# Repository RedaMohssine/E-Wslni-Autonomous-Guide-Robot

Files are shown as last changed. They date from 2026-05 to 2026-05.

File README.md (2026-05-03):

# E-Wslni — Autonomous Campus Guide Robot

> **E-Wslni** (وصلني) is Moroccan Darija for *"Take me there"* — an autonomous indoor guide robot developed at [EMINES School of Industrial Management, UM6P](https://www.emines-ingenieur.org/) as a 1-year engineering capstone project.

---

## Table of Contents

- [Overview](#overview)
- [System Architecture](#system-architecture)
- [Modules](#modules)
  - [Hardware & Firmware](#hardware--firmware)
  - [SLAM Mapping](#slam-mapping)
  - [Autonomous Navigation — Nav2](#autonomous-navigation--nav2)
  - [AI Chatbot Interface](#ai-chatbot-interface)
- [In Action](#in-action)
- [Tech Stack](#tech-stack)
- [Getting Started](#getting-started)
  - [Prerequisites](#prerequisites)
  - [1 — SLAM Mapping](#1--slam-mapping)
  - [2 — Autonomous Navigation](#2--autonomous-navigation)
  - [3 — Chatbot Interface](#3--chatbot-interface)
- [Project Documents](#project-documents)
- [Repository Structure](#repository-structure)
- [Team](#team)

---

## Overview

E-Wslni is a full-stack autonomous guide robot that lets campus visitors ask questions or request navigation to any location by voice or text. The robot:

1. **Maps** the campus autonomously using a 2D LiDAR and SLAM
2. **Localizes** itself in real-time within that map
3. **Understands** natural-language requests in French, English, and Arabic
4. **Navigates** autonomously to the requested destination using Nav2
5. **Responds** via synthesized speech in the visitor's language

---

## System Architecture

The system is divided into four integrated layers:

| Layer | Technology | Role |
|---|---|---|
| **Hardware** | Arduino Mega 2560 + MPU-6050 | Low-level motor control, odometry, anomaly detection |
| **Compute** | Lenovo ThinkCentre Mini PC, Ubuntu 22.04) | Runs ROS2, SLAM, Nav2, vision |
| **Perception** | LD06 LiDAR + Logitech C920 camera | 360° 2D laser scanning + semantic obstacle detection |
| **Mapping / Navigation** | SLAM Toolbox + Nav2 | Real-time mapping & autonomous path planning |
| **Interface** | Streamlit + LangGraph + GPT-4o-mini | Conversational AI with voice I/O |

Communication between the chatbot (which can run on any machine) and the robot passes through a lightweight **FastAPI WebSocket hub** deployed on Railway.

---

## Modules

### Hardware & Firmware

**File:** [`arduino.ino`](arduino.ino)  
**Hardware:** Arduino Mega 2560, MPU-6050 IMU, 2× DC motors with quadrature encoders, 12 V Li-ion motor battery

The main firmware handles:

- **Differential drive control** — independent left/right DC motors, PWM + PID with feedforward, adaptive filtering
- **Wheel geometry** — wheel radius 0.10 m, wheelbase (entraxe) 0.488 m
- **Odometry** — quadrature encoders (64 CPR) sampled at 128 Hz; velocity published to ROS2 at 57600 baud
- **Anomaly detection** via MPU-6050:
  - Tilt / rollover detection (gyro X/Y rates)
  - Floor bump detection (accelerometer Z deviation from baseline)
  - Wheel-slip detection (gyro yaw vs. encoder-computed yaw divergence); PID gain reduced to 60 % on slip
- **Battery management** — 12 V Li-ion monitoring with relay cutoff at 11 V (motors disconnected during charge)
- **Angular correction loop** — PI controller (Kp=0.8, Ki=1.5) to compensate mechanical asymmetries
- **Serial protocol** — speed + angular velocity commands; telemetry at 128 Hz

**CAD Design:** [`SolidWorks CAD/`](SolidWorks%20CAD/)  
60+ SolidWorks parts and assemblies covering the octagonal chassis (HPL 8 mm panels, steel square-tube frame), motor mounts, wheel sub-assemblies (axle + pillow-block bearings + flexible coupling), LiDAR/screen enclosure, camera support, charging port, and the automatic charging station.

| Real Robot | SolidWorks CAD Model |
|:---:|:---:|
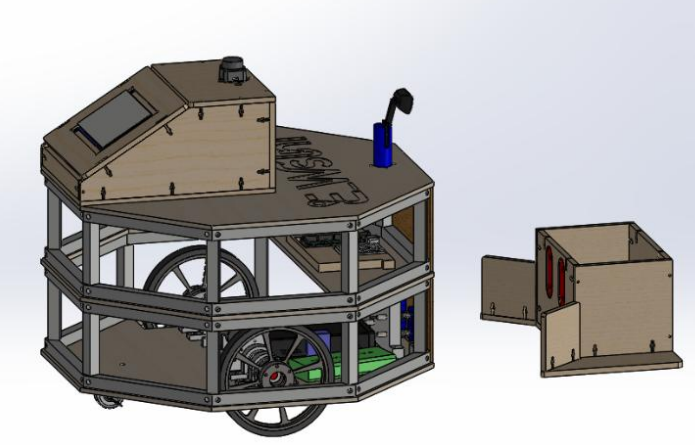
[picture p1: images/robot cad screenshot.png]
SolidWorks full-assembly render of E-Wslni showing chassis layers, wheel assembly, and electronics enclosure
| E-Wslni — octagonal laser-cut chassis with LD06 LiDAR and electronics box on top |  |
| *The physical robot: octagonal laser-cut chassis, dual DC drive wheels, and the electronics enclosure housing the LD06 LiDAR on top.* | *SolidWorks full assembly — chassis layers, motor mounts, drive wheels, LiDAR mount, and the detachable electronics box.* |

---

### SLAM Mapping

**Directory:** [`Mapping (SLAM)/`](Mapping%20(SLAM)/)  
**Stack:** ROS2 Humble · SLAM Toolbox · LD06 LiDAR · Arduino Uno

The SLAM module builds a persistent 2D occupancy map of the campus while the operator teleoperates the robot.

#### Key files

| File | Role |
|---|---|
| `src/ldlidar_stl_ros2/` | LD06 LiDAR ROS2 driver (C++) — publishes `/scan` at 230400 baud |
| `scripts/arduino_bridge.py` | Reads encoder ticks from Arduino, publishes `/odom` with differential drive kinematics |
| `scripts/keyboard_teleop.py` | AZERTY keyboard teleoperation for manual mapping runs |
| `hardware_r/robot_control.ino` | Arduino Uno sketch used during SLAM (speed + steering protocol) |
| `config/mapper_params_online_async.yaml` | SLAM Toolbox parameters (resolution, range, loop closure) |
| `config/slam_toolbox.rviz` | RViz layout for real-time map visualization |
| `launch/robot_slam_launch.py` | All-in-one launch: LiDAR + Arduino bridge + SLAM Toolbox |

#### TF tree

```
map → odom → base_footprint → base_link → base_laser
```

#### Quick start

```bash
# 1. Give serial permissions (once)
sudo chmod 666 /dev/ttyUSB0 /dev/ttyACM0
# or install persistent udev rules:
sudo bash scripts/create_udev_rules.sh

# 2. Upload robot_control.ino to Arduino Uno via Arduino IDE

# 3. Build the ROS2 workspace
cd "Mapping (SLAM)/ld06_reel_plateforme_mobile/LD06_SLAM_Robot_Clean"
source /opt/ros/humble/setup.bash
rosdep install --from-paths src --ignore-src -y
colcon build --symlink-install
source install/setup.bash

# 4. Launch everything
ros2 launch launch/robot_slam_launch.py

# 5. Teleoperate with AZERTY keyboard (separate terminal)
python3 scripts/keyboard_teleop.py
```

| Key | Action |
|-----|---|
| `Z` | Forward |
| `S` | Backward |
| `Q` | Turn left |
| `D` | Turn right |
| `Space` | Stop |

#### Save the map

```bash
ros2 run nav2_map_server map_saver_cli -f ~/campus_map
# Produces: campus_map.pgm + campus_map.yaml
```

#### Result — EMINES campus map

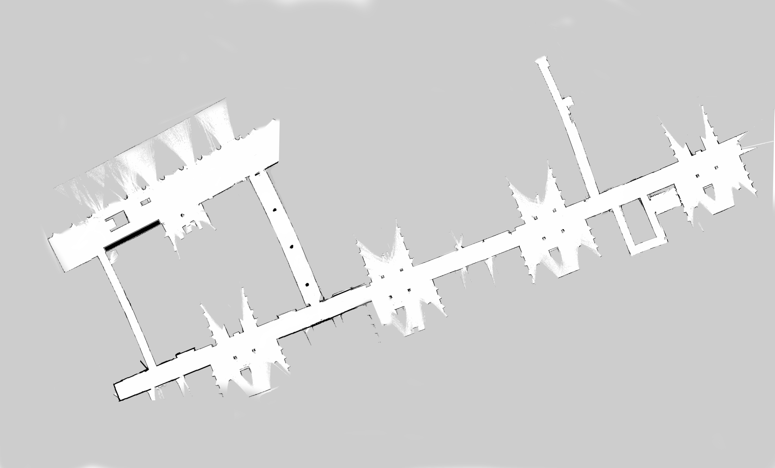
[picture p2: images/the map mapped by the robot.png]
2D occupancy map of the EMINES campus corridors and rooms, generated by SLAM Toolbox with the LD06 LiDAR


*Full occupancy map of the EMINES building generated during a teleoperated mapping run. White = free space, black = walls/obstacles, grey = unexplored. The map captures the main corridors, room doorways, and open areas across the floor.*

---

### Autonomous Navigation — Nav2

**Directory:** [`Navigation (NAV2)/`](Navigation%20(NAV2)/)  
**Stack:** ROS2 Humble · Nav2 · Gazebo (simulation) · pre-built campus map

The navigation module uses the map saved during SLAM to localize the robot (AMCL) and plan collision-free paths to goal positions sent by the chatbot.

#### Key source packages

| Package | Role |
|---|---|
| `robot_hardware/` | Translates Nav2 `cmd_vel` → Arduino serial commands; publishes encoder odometry |
| `robot_navigation/` | Nav2 parameter file (`nav2_params.yaml`) and launch |
| `robot_navigation2/` | Alternative Nav2 configurations (localization-only, minimal, complete) |
| `robot_simulation/` | Gazebo world + robot URDF for simulation-based testing |

#### Utility scripts

| Script | Purpose |
|---|---|
| `map_scale_calibrator.py` | Interactive GUI — click known distances on the PGM map to calibrate resolution |
| `teamviewer.py` | Terminal HUD with real-time speed/turn bars for manual control |

#### Nav2 in action — local costmap and trajectory planning

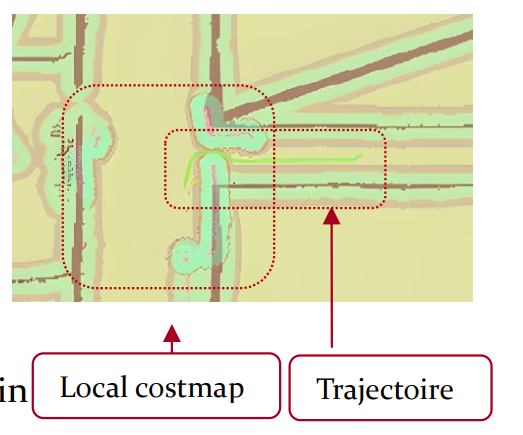
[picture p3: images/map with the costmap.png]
Nav2 local costmap overlaid on the campus map, with the planned trajectory shown through a corridor


*Nav2 running on the real robot: the coloured overlay is the **local costmap** (inflation layers around obstacles in green/brown), and the planned **trajectory** shows the route the robot is following through the corridor. The DWB planner replans dynamically at each control step.*

#### Quick start (real robot)

```bash
cd "Navigation (NAV2)/slam"
source /opt/ros/humble/setup.bash
source test/install/setup.bash

# Launch navigation with saved map
ros2 launch robot_hardware real_robot_nav.launch.py map:=test/maps/slam_map.yaml
```

#### Quick start (simulation)

```bash
cd "Navigation (NAV2)/slam/test"
source /opt/ros/humble/setup.bash
source install/setup.bash

ros2 launch robot_simulation gazebo.launch.py
ros2 launch robot_navigation2 nav2.launch.py use_sim_time:=true
```

---

### AI Chatbot Interface

**Directory:** [`UI + Chatbot/`](UI%20+%20Chatbot/)  
**Stack:** Streamlit · LangGraph · LangChain · OpenAI GPT-4o-mini · Whisper · Cartesia · Chroma · FastAPI

The chatbot is a Streamlit web application that gives visitors a conversational interface — by text or voice — to query the campus knowledge base and request autonomous navigation.

#### Architecture

```
User (browser)
    │  voice / text
    ▼
Streamlit UI  ──────────────────────────────────────┐
    │                                                │
    ▼                                                │
LangGraph Workflow                                   │
    ├─ AudioWorkflow: STT (Whisper) → LLM → TTS     │
    └─ ChatWorkflow:  text → LLM                     │
              │                                      │
              ▼                                      │
         GPT-4o-mini (tool use)                      │
          ├─ document_retriever  ←── Chroma RAG      │
          └─ navigation_tool                         │
                    │                                │
                    ▼                                │
            FastAPI Hub (Railway) ◄──────────────────┘
                    │
                    ▼
              Robot (Nav2 goal)
```

#### User Interface

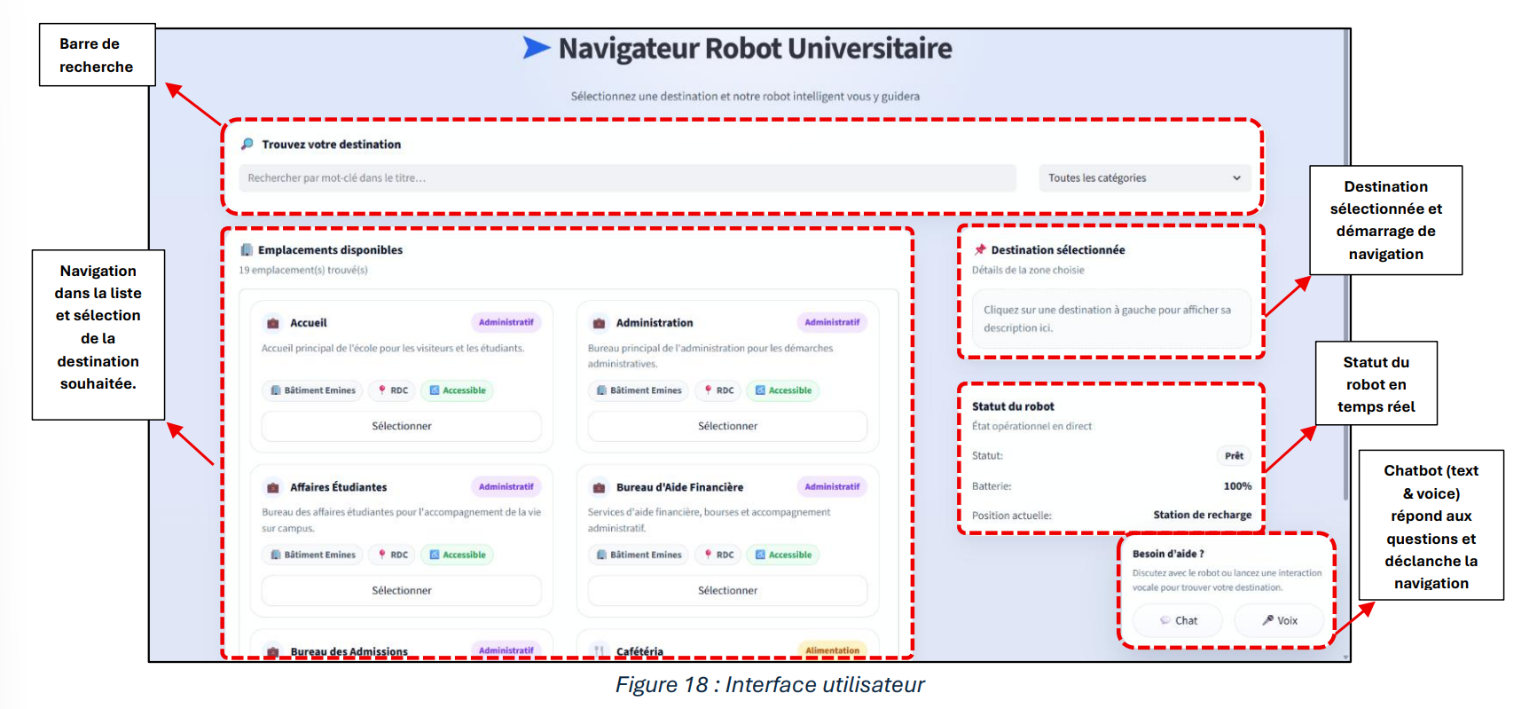
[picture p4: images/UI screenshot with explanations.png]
Streamlit chatbot UI — destination search panel, locations list, robot status card, and the voice/chat assistant widget


*The desktop interface — **"Navigateur Robot Universitaire"**:*
- **(Left) Location browser** — searchable list of all 19+ campus destinations, filterable by category (Administrative, Food, Labs, Clubs…). Click any card to select it.*
- **(Top-right) Destination panel** — shows details of the selected destination and triggers navigation on the robot.*
- **(Mid-right) Robot status** — live connection status, battery level, and current position reported by the robot.*
- **(Bottom-right) AI Assistant** — switch between **Chat** (text) and **Voice** modes. Voice input is transcribed by Whisper, answered by GPT-4o-mini in the visitor's language (FR/EN/AR), and spoken back through the robot's speaker via Cartesia TTS.*

#### Key files

| File | Role |
|---|---|
| `streamlit_app.py` | Entry point |
| `src/workflow.py` | LangGraph state machine — routes audio/text, calls tools |
| `src/services/llm.py` | GPT-4o-mini agent with two tools: RAG retrieval + navigation dispatch |
| `src/services/navigation.py` | Fuzzy location matching + WebSocket dispatch to robot |
| `src/services/rag.py` | OpenAI embeddings + Chroma vector search over campus docs |
| `src/services/stt.py` | Whisper-1 speech-to-text with campus proper-noun prompt biasing |
| `src/services/tts.py` | Cartesia text-to-speech (French/English/Arabic routing) |
| `src/services/memory.py` | Conversation history persistence |
| `src/ui/app_desktop.py` | Main Streamlit page — chat widget, voice orb, navigation card |
| `hub/main.py` | FastAPI WebSocket relay between chatbot and robot |
| `vectordb_generation.py` | One-time script to index campus documents into Chroma |
| `data/locations.json` | Campus destinations catalog (name, aliases, coordinates, category) |
| `data/*.md` | EMINES programs and campus knowledge base |

#### Setup

```bash
cd "UI + Chatbot"
python -m venv .venv
source .venv/bin/activate          # Windows: .venv\Scripts\activate
pip install -e .
```

Create a `.env` file:

```env
OPENAI_API_KEY=sk-...
ASSEMBLYAI_API_KEY=...
CARTESIA_API_KEY=...
HUB_URL=wss://your-hub.railway.app/ws/robot   # optional: only for live robot
HUB_TOKEN=...                                   # optional
```

Build the RAG index (first time only):

```bash
python vectordb_generation.py
```

Run the app:

```bash
streamlit run streamlit_app.py
```

#### Deploy the hub (Railway)

```bash
cd hub
# Push to Railway — Procfile and railway.json are included
```

---

## In Action

The robot navigating autonomously through EMINES corridors and doorways:

| Approaching a doorway | Crossing through |
|:---:|:---:|
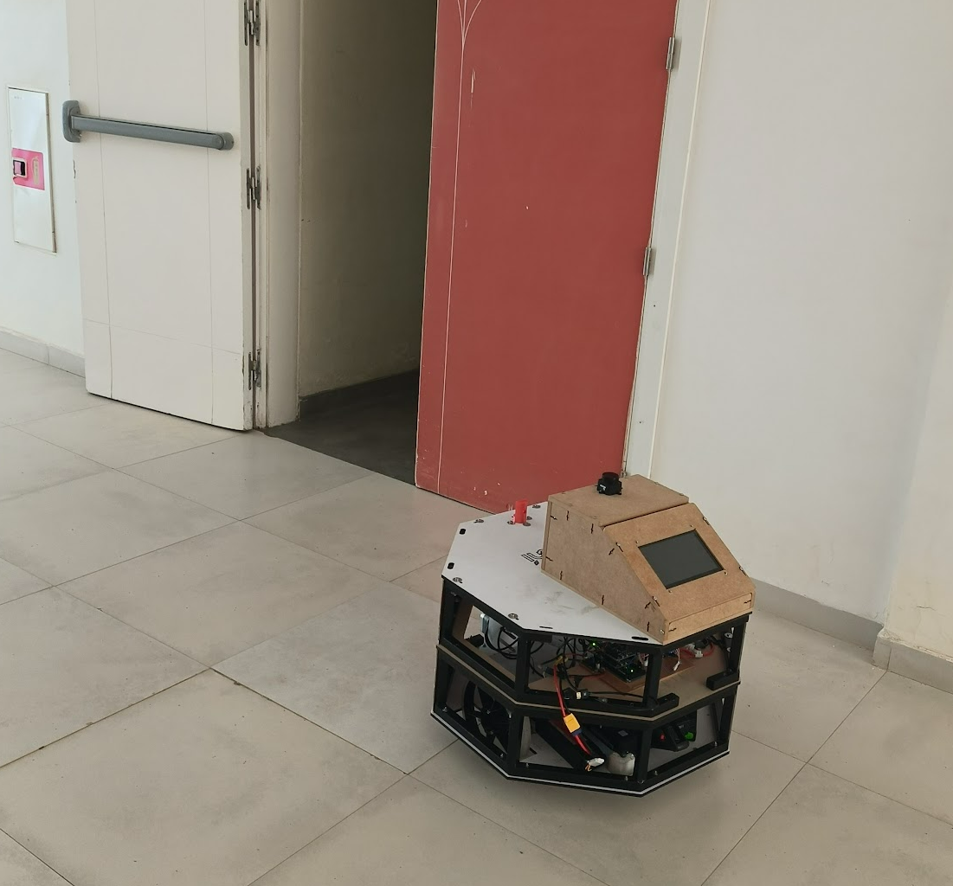
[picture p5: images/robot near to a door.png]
E-Wslni approaching an open doorway in an EMINES corridor, aligned by the Nav2 local planner
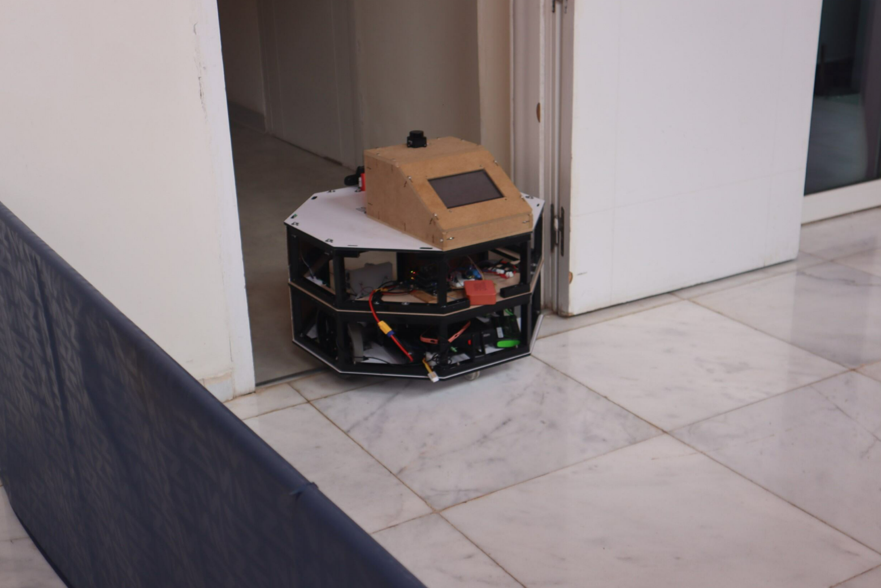
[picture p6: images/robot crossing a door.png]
E-Wslni successfully crossing through a doorway, demonstrating narrow-passage navigation
|  |  |
| *Robot approaching an open doorway — the Nav2 local planner aligns the robot with the gap while continuously replanning around the door-frame obstacle.* | *Robot threading through the doorway — demonstrating the clearance margins achieved by the DWB planner and the differential drive kinematics.* |

---

## Tech Stack

| Domain | Technology |
|---|---|
| Robot OS | ROS2 Humble (Ubuntu 22.04) |
| SLAM | SLAM Toolbox |
| Navigation | Nav2 (costmaps, DWB planner, AMCL) |
| Simulation | Gazebo |
| LiDAR | LD06 (12 m range, 360°, 10 Hz) |
| Microcontroller | Arduino Mega 2560 |
| IMU | MPU-6050 (gyro + accelerometer) |
| LLM | OpenAI GPT-4o-mini |
| Orchestration | LangChain + LangGraph |
| Vector DB | Chroma |
| STT | OpenAI Whisper-1 |
| TTS | Cartesia |
| UI Framework | Streamlit |
| Hub | FastAPI + WebSockets (Railway) |
| CAD | SolidWorks |
| Languages | Python 3.11 · C++ · C (Arduino) |

---

## Getting Started

### Prerequisites

- **Ubuntu 22.04** for the robot (ROS2 / Nav2)
- **Python 3.11+** for the chatbot (any OS)
- **ROS2 Humble** — [install guide](https://docs.ros.org/en/humble/Installation.html)
- **Arduino IDE** — for firmware upload
- API keys: OpenAI, Cartesia

### 1 — SLAM Mapping

See [SLAM Mapping](#slam-mapping) section above.

### 2 — Autonomous Navigation

See [Autonomous Navigation](#autonomous-navigation--nav2) section above.

### 3 — Chatbot Interface

See [AI Chatbot Interface](#ai-chatbot-interface) section above.

---

## Project Documents

The full technical documentation for this project is included at the root of the repository:

| Document | Description |
|---|---|
| [📄 Dossier de définition](Dossier%20de%20d%C3%A9finition.pdf) | Project definition document — functional requirements, system specifications, design choices, and technical architecture |
| [📊 Présentation soutenance 2](Pr%C3%A9sentation%20soutenance%202%20guide%20intelligent.pdf) | Final presentation slides — project overview, results, and demonstrations |

---

## Repository Structure

```
Autonomous-Guide-Robot-E-Wslni/
│
├── arduino.ino                          # Arduino Mega 2560 main firmware
├── Dossier de définition.pdf            # Project definition document
├── Présentation soutenance 2 guide intelligent.pdf
│
├── images/                              # Project photos and screenshots
│   ├── robot image .JPG                 # Physical robot photo
│   ├── robot cad screenshot.png         # SolidWorks CAD render
│   ├── the map mapped by the robot.png  # SLAM occupancy map result
│   ├── map with the costmap.png         # Nav2 costmap + trajectory
│   ├── UI screenshot with explanations.png  # Annotated chatbot UI
│   ├── robot near to a door.png         # Robot approaching a doorway
│   ├── robot crossing a door.png        # Robot crossing a doorway
│   └── photo of our team and professors.JPG # Team photo
│
├── SolidWorks CAD/                      # 60+ mechanical parts & assemblies
│
├── Mapping (SLAM)/
│   └── ld06_reel_plateforme_mobile/
│       └── LD06_SLAM_Robot_Clean/
│           ├── src/ldlidar_stl_ros2/    # LD06 LiDAR ROS2 driver (C++)
│           ├── scripts/
│           │   ├── arduino_bridge.py    # Odometry publisher (Ackermann kinematics)
│           │   └── keyboard_teleop.py   # Manual AZERTY teleoperation
│           ├── config/                  # SLAM Toolbox + RViz configs
│           ├── launch/                  # ROS2 launch files
│           └── hardware_r/
│               └── robot_control.ino    # Arduino Uno SLAM-mode firmware
│
├── Navigation (NAV2)/
│   └── slam/
│       ├── map_scale_calibrator.py      # Map resolution calibration GUI
│       ├── teamviewer.py                # Interactive terminal controller
│       └── test/src/
│           ├── robot_hardware/          # cmd_vel → Arduino, encoder odometry
│           ├── robot_navigation/        # Nav2 parameter files
│           ├── robot_navigation2/       # Nav2 launch configurations
│           └── robot_simulation/        # Gazebo world + robot URDF
│
└── UI + Chatbot/
    ├── streamlit_app.py                 # Entry point
    ├── vectordb_generation.py           # RAG index builder
    ├── hub/main.py                      # FastAPI WebSocket relay (Railway)
    ├── src/
    │   ├── workflow.py                  # LangGraph state machine
    │   ├── models.py                    # Data models
    │   ├── services/                    # LLM · RAG · STT · TTS · Navigation · Memory
    │   ├── ui/                          # Streamlit pages & CSS
    │   └── components/                  # Custom voice orb component
    └── data/
        ├── locations.json               # Campus destinations catalog
        └── *.md                         # EMINES campus knowledge base
```

---

## Team

Developed at **EMINES School of Industrial Management — UM6P** (2024–2025).

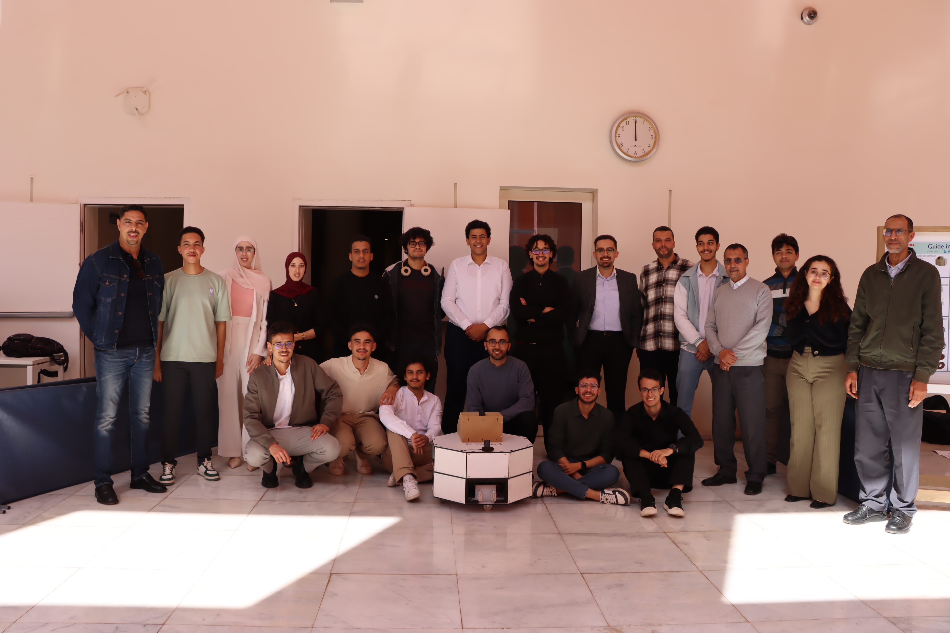
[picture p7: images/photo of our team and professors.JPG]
The E-Wslni project team and supervising professors gathered around the robot at EMINES, UM6P, Ben Guerir


*The E-Wslni team and supervising professors at EMINES — Université Mohammed VI Polytechnique, Ben Guerir, Morocco.*

<!-- Add your team members here -->
<!--
| Name | Role |
|---|---|
| ... | ... |
-->

---

*EMINES — École De Management Industriel, Université Mohammed VI Polytechnique, Ben Guerir, Morocco.*

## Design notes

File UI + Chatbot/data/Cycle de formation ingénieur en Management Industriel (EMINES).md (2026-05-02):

# Contexte de la création de l’Emines

L’Afrique est une multitude. Cet immense continent, berceau de l’humanité, comptant cinquante-quatre états, deux mille langues, mille groupes ethniques, trente millions de kilomètres carrés et une population qui devrait doubler d’ici 2050, est un espace complexe, qui doit faire face à des défis majeurs pour consolider sa propre dynamique de développement. La révolution numérique actuelle qui transforme les chaînes de valeur au niveau mondial et le développement des compétences est un de ces défis.

Pour l’Afrique, c’est l’opportunité d’être créatrice de valeur dans les industries traditionnelles telles que le secteur manufacturier, mais également dans d’autres secteurs et activités essentiels au développement industriel tels que la logistique, l’agriculture, l’énergie, les communications, les services, la croissance verte et les villes intelligentes. Le continent africain, fort de son histoire et de son potentiel, dispose d’un ensemble d’atouts majeurs pour inventer son propre modèle d’industrialisation durable.

Pour cela, ce continent doit transformer ses modèles d’éducation afin de former les talents qui contribueront à écrire cet avenir. Il doit notamment pouvoir s’appuyer sur des ingénieurs de haut niveau scientifique, inventifs, créatifs et entrepreneurs qui sauront conduire le progrès en Afrique.

# Vocation de l’EMINES :

L’EMINES - School of Industrial Management a pour vocation de :
- **Former les futurs leaders des entreprises**
Des ingénieurs-managers maîtrisant les savoirs scientifiques/techniques de base et préparés à l'entrepreneuriat panafricain
- **Développer une recherche impactante**
Programmes de recherche alignés sur les besoins concrets des entreprises africaines

Pour répondre à ces deux missions, la School of Industrial Management base son développement sur :
- **Formations pratiques :** Une pédagogie résolument orientée projets en équipe et au moins 42 semaines de stage dont un tiers à l'étranger
- **Recherche appliquée :** Partenariats entreprises avec utilisation d'outils de simulation pour résoudre des problèmes réels
- **Excellence académique :** Collaboration avec MINES Paris - PSL, Ecole Polytechnique ainsi qu'un réseau international d'enseignants-chercheurs
- **Culture entrepreneuriale :** Préparation aux réalités économiques mondiales et développement de compétences multiculturelles

# Le profil des ingénieurs de l’EMINES découle logiquement de cette vocation/ PROFIL DE L'INGENIEUR DE L'EMINES :

DIGITAL, INTERCULTUREL, ENTREPRENEUR, MANAGER, SCIENTIFIQUE

Au sein de l’Université Mohammed 6 Polytechnique (UM6P), l’EMINES met ainsi en œuvre deux principes fondateurs de cette université: le développement des talents au service de l’Afrique et une pédagogie originale basée sur le learning by doing.

L'EMINES offre ainsi à ses élèves-ingénieurs une formation fondamentale scientifique, technique et socio-économique, marquée par l'excellence académique, appuyée sur un fort développement de savoir-faire pratique et de savoir-être.
Sa Majesté le Roi Mohammed VI a procédé jeudi 12/01/2017 à l’inauguration de l’Université Mohammed VI Polytechnique.

# Campus de l’EMINES – UM6P :
Au-delà de la vie académique, l’EMINES-School of Industrial Management est un véritable espace de vie en communauté, qui est situé sur le campus de 35 hectares de l’Université Mohammed VI Polytechnique au cœur de la future ville verte de Benguérir et à proximité de Marrakech.

Ce campus offre une qualité d’<u>hébergement et de restauration</u> aux standards internationaux.
Par ailleurs, il permet une pratique active du sport qui est une composante importante de la pédagogie de la School of Industrial Management.

**Les installations sportives :**
Le campus dispose d’infrastructures sportives de grande qualité, en intérieur et en extérieur.
* 5000 m² de terrains sportifs en plein air dont :
    - 2 terrains de mini foot gazonnés
    - 4 terrains omnisport (tennis, basket, volley hand-ball)
* Une piscine semi olympique de 25 m et un bassin d’apprentissage
* Une salle de fitness
* Une salle de musculation
* Une salle de danse
* Une salle de sport de combat

Enfin, La bibliothèque est située au coeur de la vie de la School of Industrial Management.
Son but est de favoriser l'accès à la culture, à la connaissance et à l'information scientifique et technique.

Elle propose pour l'instant environ 12 000 ouvrages couvrant tous les domaines de spécialités de l'école, ainsi qu'une collection d'ouvrages de culture générale (romans, littérature, revues, histoire...). Lien direct vers <u>le site de la Bibliothèque</u> : https://learningcenter.um6p.ma/

Le fonds documentaire est répertorié dans une base de données. Les étudiants, enseignants et chercheurs de l'école peuvent consulter le catalogue en ligne de n'importe quel point du campus.

Enfin, une équipe de documentalistes se tient à la disposition des utilisateurs pour les accueillir, les informer, les guider dans leurs recherches, et recueillir leurs suggestions.

# Accessibilité et transports
<table>
  <tbody>
    <tr>
        <td>EMINES</td>
        <td>-</td>
        <td>Université Mohammed VI Polytechnique</td>
    </tr>
    <tr>
        <td>LOT 660</td>
        <td>-</td>
        <td>HAY MOULAY RACHID</td>
    </tr>
    <tr>
        <td>43150</td>
        <td></td>
        <td>BEN GUERIR</td>
    </tr>
    <tr>
        <td>MAROC</td>
        <td colspan="2"></td>
    </tr>
  </tbody>
</table>

* En voiture : Ben Guerir se situe à 40 minutes au nord de Marrakech, sur l'Autoroute de Casablanca.
* En train : la gare de Ben Guérir est à 50 mn de Marrakech et à 2h10 de Casablanca (8 trains par jour)
* L'aéroport international de Marrakech est à 1h00 ; l’aéroport international de Casablanca est à 2h00 ; chacun d’eux propose de nombreuses liaisons quotidiennes avec les grandes villes d'Europe.

# LOGEMENT et Restauration à l’EMINES :

## La résidence étudiante

Les élèves de l’EMINES – School of Industrial sont logés au sein de résidences sur le campus de Ben Guérir. Les logements sont organisés en appartements de 4 chambres individuelles, avec un salon commun équipé d'un coin cuisine équipé. Chaque chambre est individuelle et est meublée. Elle dispose d'une salle de bain avec WC et douche. L’accès internet Haut Débit et une ligne téléphonique sont présents dans tous les logements. Chaque résidence possède une salle de détente avec télévision, une salle de jeu avec billard, babyfoot et pingpong. Enfin un service de buanderie (lave-linges et sèche-linges) est disponible dans chaque résidence. Des chambres sont prévues pour l’accès et l’hébergement de personnes à mobilité réduite.

## Restauration

Les élèves de l’EMINES - School of Industrial Management ont accès à un restaurant, avec des menus variés, équilibrés et diététiques. Ce restaurant sert les petits déjeuners, les déjeuners et les diners avec des plages d’ouverture larges permettant à chaque élève de se restaurer selon son rythme.

# Les information sur le Cycle Préparatoire Intégré (1<sup>er</sup> année et 2eme année prepa)

Les quatre semestres de formation du Cycle Préparatoire Intégré de l’EMINES ont pour objectif d’accroître significativement le niveau des connaissances des bacheliers dans différents champs disciplinaires de manière à les rendre aptes à suivre le Cycle Ingénieur. Les Matière étudié et leur répartition du volume horaire :

- Anglais 10%
- Sport 3%
- Physique Expérimentale 13%
- Français 10%
- Physique Classique 16%
- Projet d'Ingénierie 19%
- Mathématiques 23%
- Informatique 6%

# Cycle Ingénieur 180 ECTS (6 semestres de 30 ECTS – 3 ans)

La progression pédagogique du Cycle Ingénieur est construite de manière à permettre à chaque élève ingénieur d’acquérir les différentes compétences attendues d’un diplômé de l’EMINES.

## Scientifique

En Première année cycle ingenieur à emines, on etudie :

- Calcul Différentiel
- Calcul Intégral
- Economie Générale
- Mécanique
- Chimie Industrielle

- Thermodynamique Industrielle

Deuxième année cycle ingenieur à emines, on etudie :
- Probabilités - Statistiques
- Data Science*, Mécanique des fluides*, Nanotechnologies*, Cosmologie*, Energie renouvelable*

Troisième année cycle ingenieur à emines, on etudie :
- Développement Durable - Etude d'Option (PFE)

# MANAGER

Première année cycle ingenieur à emines, on etudie :
- Stage d'observation en Géologie
- Recherche Opérationnelle
- Biomedical engineering
- Module d'Initiation au Management Industriel
- Description de Controverses

Deuxième année cycle ingenieur à emines, on etudie :
- Systèmes de Production et Logistique
- Évaluation des coûts
- Mécatronique
- Stratégie minière
- Management hospitalier*

Troisième année cycle ingenieur à emines, on etudie :
- Stratégie d'entreprise
- Droit / Comptabilité / GRH / Achats / Finance d'entreprise
- Lean Management
- Maintenance industrielle 4.0
- Etude d'Option (PFE)

# Digital

Première année cycle ingenieur à emines, on etudie :
- Python, Java, SQL, HTML/PHP

Deuxième année cycle ingenieur à emines, on etudie :
- Analytic Edge
- Mécatronique
- Automatique
- Cryptographie*, Cyber sécurité*
- VBA

Troisième année cycle ingenieur à emines, on etudie
- Sureté de fonctionnement*
- ERP/SAP
- Etude d'Option (PFE)

# ENTREPRENEUR

Première année cycle ingenieur à emines, on etudie :
- Acte d'Entreprendre I
- Entrepreneurship week

Deuxième année cycle ingenieur à emines, on etudie :
- Gestion de projet*
- Réseaux socio-numériques*
- Acte d'Entreprendre II*
- Année de césure

Troisième année cycle ingenieur à emines, on etudie :
- Business Game
- Etude d'Option (PFE)

# Interculturel

Première année cycle ingenieur à emines, on etudie
- Anglais
- LV2 (Mandarin / Espagnol)
- Sport
- Stage d'exécution

Deuxième année cycle ingenieur à emines, on etudie :
- Anglais
- LV2 (Mandarin / Espagnol)
- Sport
- Shadowing
- Mobilité à l'international

Troisième année cycle ingenieur à emines, on etudie :
- Développement personnel par le théâtre
- Intelligence collective
- Préparation à la vie professionnelle
- Préparation au TOEIC - Etude d'Option (PFE)
- 

# L'option en 5éme année à l'emines

Le cycle Ingénieur de l'EMINES offre une filière généraliste unique : Management Industriel. Les étudiants doivent néanmoins choisir en dernière année une option destinée à appliquer leurs acquis à un domaine particulier. L'option est constituée de 8 semaines de formation, et assure l'encadrement académique du projet de fin d'étude en entreprise. L'Option va permettre à chaque élève ingénieur de mettre en oeuvre les compétences acquises durant son cursus dans un domaine de son choix, sans pour autant préjuger d'une orientation professionnelle définitive L'étude d'option clôture la scolarité et atteste de la compétence d'un élève ingénieur à savoir modéliser un problème complexe en contexte réel et à y apporter une solution innovante avec une mise en oeuvre concrète dans l'entreprise d'accueil.

Il existe 4 options à emines :
- OPTION SUPPLY CHAIN MANAGEMENT

Responsables : Frédéric FONTANE (Directeur Adjoint Mines ParisTech) ; et Ahlam EZZAMOURI (Prof EMINES-UM6P)
- OPTION MINING
Responsables : Damien GOETZ (Pr. Mines ParisTech) ; et Ismail AKALAY (DG. SONASID)
- OPTION DATA SCIENCES INDUSTRIELLES
Responsables : Eric MOULINES (Pr. Ecole Polytechnique) ; et Geneviève ROBIN (Dr. CNRS)
- OPTION MANAGEMENT DES ENTREPRISES INNOVANTES
Responsables : Michel BERRY (Directeur de l’Ecole de Paris du Management) Christophe DESHAYES (Ing à Ecole de Paris du Management)

# OPTION SUPPLY CHAIN MANAGEMENT
Responsable : Frédéric FONTANE (Directeur Adjoint Mines ParisTech)

<table>
  <thead>
    <tr>
        <th>Semaine</th>
        <th>Contenu</th>
    </tr>
  </thead>
  <tbody>
    <tr>
        <td>Semaine 1</td>
        <td>Enjeux industriels et logistiques</td>
    </tr>
    <tr>
        <td>Semaine 2</td>
        <td>Planification industrielle et gestion de projet</td>
    </tr>
    <tr>
        <td>Semaine 3</td>
        <td>Maintenance et Qualité</td>
    </tr>
    <tr>
        <td>Semaine 4</td>
        <td>Prévision des ventes et gestion de stock</td>
    </tr>
    <tr>
        <td>Semaine 5</td>
        <td>Chaine logistique</td>
    </tr>
    <tr>
        <td>Semaine 6</td>
        <td>Modeleur et Problem design</td>
    </tr>
    <tr>
        <td>Semaine 7</td>
        <td>Simulation à événements discrets</td>
    </tr>
    <tr>
        <td>Semaine 8</td>
        <td>Visites industrielles</td>
    </tr>
  </tbody>
</table>

# OPTION MINING
Responsables : Damien GOETZ (Pr. Mines ParisTech), Ismail AKALAY (DG. SONASID)

<table>
  <thead>
    <tr>
        <th>Semaine</th>
        <th>Contenu</th>
    </tr>
  </thead>
  <tbody>
    <tr>
        <td>Semaine 1</td>
        <td>Projets miniers : de la géologie à l’exploitation</td>
    </tr>
    <tr>
        <td>Semaine 2</td>
        <td>Planification minière</td>
    </tr>
    <tr>
        <td>Semaine 3</td>
        <td>Mécanique des roches, stabilité et soutènement</td>
    </tr>
    <tr>
        <td>Semaine 4</td>
        <td>Méthodes de traitement et impacts environnementaux</td>
    </tr>
    <tr>
        <td>Semaine 5</td>
        <td>Processus achats-logistique-marketing et RSE</td>
    </tr>
    <tr>
        <td>Semaine 6</td>
        <td>Économie et sélectivité</td>
    </tr>
    <tr>
        <td>Semaine 7</td>
        <td>Visites industrielles 1</td>
    </tr>
    <tr>
        <td>Semaine 8</td>
        <td>Visites industrielles 2</td>
    </tr>
  </tbody>
</table>

# OPTION DATA SCIENCES INDUSTRIELLES
Responsables : Eric MOULINES (Pr. Ecole Polytechnique) Geneviève ROBIN (Dr. CNRS)

<table>
  <thead>
    <tr>
        <th>Semaine</th>
        <th>Contenu</th>
    </tr>
  </thead>
  <tbody>
    <tr>
        <td>Semaine 1</td>
        <td>Approfondissement en statistiques, régression linéaire et modèles linéaires généralisés</td>
    </tr>
    <tr>
        <td>Semaine 2</td>
        <td>Introduction à l’apprentissage supervisé : Arbres de classification et de régression, forêts aléatoires, méthodes ensemblistes, boosting</td>
    </tr>
    <tr>
        <td>Semaine 3</td>
        <td>Apprentissage non-supervisé : ACP, analyse factorielle, classification hiérarchique, algorithme EM</td>
    </tr>
    <tr>
        <td>Semaine 4</td>
        <td>Introduction à l’apprentissage profond</td>
    </tr>
    <tr>
        <td>Semaine 5</td>
        <td>Machines à vecteurs de support et méthodes à noyaux</td>
    </tr>
    <tr>
        <td>Semaine 6</td>
        <td>Introduction au traitement des langues naturelles</td>
    </tr>
  </tbody>
</table>

<table>
    <tr>
        <th>Semaine 7</th>
        <th>Data Analytics pour les processus industriels</th>
    </tr>
    <tr>
        <td>Semaine 8</td>
        <td>Datacamp</td>
    </tr>
</table># OPTION MANAGEMENT DES ENTREPRISES INNOVANTES

Responsables : Michel BERRY (Ecole de Paris du Management) Christophe DESHAYES (Ecole de Paris du Management)

<table>
    <tr>
        <th>Semaine 1</th>
        <th>Introduction au management, aux outils de gestion, aux technologies invisibles et aux modes managériales (Prise de recul)</th>
    </tr>
    <tr>
        <td>Semaine 2</td>
        <td>Management de l’innovation</td>
    </tr>
    <tr>
        <td>Semaine 3</td>
        <td>Gestion de projets complexes et innovants</td>
    </tr>
    <tr>
        <td>Semaine 4</td>
        <td>Entrepreneuriat – Entrepreneuriat social - Intrapreneuriat</td>
    </tr>
    <tr>
        <td>Semaine 5</td>
        <td>PrTransformation numérique et logique de plateforme</td>
    </tr>
    <tr>
        <td>Semaine 6</td>
        <td>Transition écologique et financement</td>
    </tr>
    <tr>
        <td>Semaine 7</td>
        <td>Libération des énergies – Management de proximité</td>
    </tr>
    <tr>
        <td>Semaine 8</td>
        <td>Gestion de l’extrême</td>
    </tr>
</table># Les projets a l’emines :

Cycle préparatoire intégré :
- Projet d’Ingénierie « construction de robots »
- Projet de Physique expérimentale

1ère année du cycle ingénieur
- Initiation au Management Industriel (par groupe de 10)
- Acte d’Entreprendre (individuel ou en groupe)
- Controverse (par groupe de 5)
- Informatique (Client réel)
- Mini-projet d’entrepreneuriat
- Mini-projet de mécanique
- Mini-projet d’économie

2ème année du cycle ingénieur
- Projet mécatronique (par groupe de 10)
- Projet de statistiques (par groupe de 3)

Mini-projet d’automatique
3ème année du cycle ingénieur
- Jeu d’entreprise
- Projets d’option (selon l’option choisie)

# Stages à l’emines :
1ère année du Cycle Ingénieur
- Stage ouvrier (4 semaines en entreprise)
- Visites industrielles d’Initiation au Management Industriel (1 semaine de visites)
- Stage d’observation en géologie (1 semaine de terrain)

2ème année du cycle ingénieur
- Stage de shadowing (1 semaine en entreprise)
- Mobilité à l’international d’initiation à la recherche (12 à 16 semaines en laboratoire académique ou industriel à l’étranger)

Stage long de 6 à 12 mois (césure, facultative) en entreprise entre la 2ème et la 3ème année

3ème année du cycle ingénieur
- Visites industrielles d’option (1 à 3 semaines de terrain selon l’option choisie)
- Etude d’option (24 semaines en entreprise + 1 semaine de restitution)

L’étude d’Option de troisième année du cycle ingénieur permet aux futurs ingénieurs de se confronter à une problématique réelle, afin d’analyser, d’apporter une réponse et autant que possible participer à sa mise en œuvre au sein de l’entreprise d’accueil.

L’étude d’option se distingue d’un stage par la volonté d’un partenariat effectif entre l’élève ingénieur, son tuteur industriel et son tuteur académique. Ce dernier s’assure notamment de l’adéquation du sujet aux objectifs, de l’encadrement des travaux et de la progression de l’étude, notamment par des réunions de travail régulières.

# Les liens avec le monde de la recherche à l’emines
- 12 à 16 semaines dans une université ou un laboratoire de recherche industrielle à l’étranger (entre la 2ème et la 3ème année du cycle ingénieur)
- Projets immergés dans les laboratoires de recherche OCP Africa ORANO OCP de l’Ecole et de l’UM6P, et/ou en lien avec les plates-formes technologiques de l’UM6P, Green Energy Park, Green Building Park, Ferme Expérimentale
- Majorité des enseignants issus du monde de la recherche académique ou industrielle

# Les langues :
L’apprentissage des langues s’appuie sur le Language Lab de l’UM6P. Ce dernier mobilise des méthodes pédagogiques originales et variées (théâtre, debating, Model United Nations, …).
- Anglais, outil de travail pour tous.
- Français en cycle préparatoire intégré.

- Chinois ou Espagnol au choix dans le cycle ingénieur.

# L’étranger :
- La mobilité de fin de 2ème année est volontairement orientée vers les pays à forte croissance, avenir du développement mondial et futurs partenaires économiques majeurs du Maroc : Brésil, Singapour, Mexique, Chine, Malaisie ...
- Voyages d’option (pour certaines options) à l’étranger.

# Partenariat privilégié avec l’Ecole des Mines de Paris :
- Nombreux enseignants issus de l’Ecole des Mines de Paris.
- Supports pédagogiques communs.
- Activités de recherche liées. - Encadrement d’option.

Autres partenaires universitaires :
- Partenariat de recherche et d’enseignement avec plusieurs enseignants de l’Ecole Polytechnique et du MIT.
- Partenaires divers en Amérique Latine et Asie du Sud-Est pour la mobilité internationale.

# Recherche orientée vers l’industrie
- PhD « industriel » : réalisation d’une thèse sur une problématique de recherche en management industriel d’une entreprise, encadrée par un professeur de l’EMINES. - Encadrement de recherche : recours à l’expertise des professeurs internationaux affiliés à l’EMINES sur la gestion industrielle et logistique, l’économie des matières premières, les data sciences et la modélisation.

# LES CONDITIONS DE VIE a l’Emines Vie associative
:
-Bureau Des Elèves
-Bureau Des Sports
-Bureau Des Arts (Musique, Danse, Théatre, Dessin, Photo et Vidéo)
-EMINES Technology (E-Tech, EMINES Solar Car, E-Social Entrepreneurship)
-E-Solidarity (E-Olives, Caravane du sourire, Soutien scolaire) -E-Junior Entreprise, Great debaters, MUN, E-Astro, ...

Hébergement et restauration :
-Les résidences étudiantes affectée à l’EMINES comptent 300 chambres -Cafétéria et restaurant universitaires.

Le sport :
-Les installations sportives de l’UM6P ont été particulièrement soignées. Ainsi, une piscine couverte, 6 terrains multisport, une salle de musculation et une salle de cardio ont été construits.

L’école est également membre du Cartel des Mines, association réunissant une fois par an les étudiants sportifs des Ecoles des Mines françaises, espagnoles, allemandes, italiennes, anglaises et russes.

-Enfin, l’ecole participe aux différentes compétitions et tournois universitaires Marocains.

## Accessibilité et transports
-Ben Guerir se situe à 1 heure de Marrakech et bénéficie ainsi de la proximité avec cette grande ville et les autres universités qui s’y trouvent.
-De plus, l’EMINES est facilement accessible par autoroute et par train. Les aéroports de Marrakech et Casablanca se trouvent aussi à proximité.

# Frais de scolarité et Bourses à l’emines :
**FRAIS DE PREMIERE INSCRIPTION**
* 5 000 Dhs

**FRAIS DE SCOLARITÉ**
* 75 000 Dhs par an pour le cycle préparatoire intégré et le cycle ingenieur

**FRAIS D'HÉBERGEMENT**
* 1 000 Dhs par mois pour une chambre individuelle dans un appartement de 4 chambres, dans la résidence du campus

**RESTAURATION**
* Les repas peuvent être pris dans les cafétérias et restaurants de l’Université
* Les appartements (groupes de chambres individuelles) sont équipés d’une cuisine, et permettent donc aux étudiants qui le désirent d'être autonomes pour tout ou partie de leurs repas.

**BOURSES**
* Quelques **bourses d’excellence**, couvrant 25%, 50%, 75% ou 100% des frais de scolarité, sont attribuées en fonction des résultats au concours d'entrée à l'école pour l’ensemble de la scolarité.
* Le cas d’élèves en difficulté financière sera examiné par la Commission des bourses qui pourra accorder une **bourse sociale**, pouvant couvrir jusqu'à 100% des frais de scolarité, d'inscription, de logement, et de nourriture.
* Les bourses d’excellence et les bourses sociales sont **cumulables**.

# Partenariats Universitaires de l’EMINES
L’EMINES – School of Industrial Management est ouverte sur le monde de l'excellence au travers de ses partenariats académiques :

**Partenariat privilégié avec MINES PARISTECH :**
* Nombreux enseignants issus de l’Ecole des Mines de Paris
* Supports pédagogiques communs
* Activités de recherche liée
* Co-encadrement des deux options Supply Chain Management & Ressources Minérales pour la Transition Energétique
* Chaire « Ressources minérales pour la transition énergétique » signée en 2024 pour une durée de 5 ans. Ce programme de recherche porte sur les thématiques de la disponibilité des ressources, du recyclage des matériaux et de la gestion de la raréfaction.

## Partenariat avec l'École polytechnique :
* Chaire « Data Science & Processus Industriels » signée en 2018 et renouvelée en 2022 pour 5 ans :
    - Co-encadrement et enseignement dans l'option Data Science
    - Activités de recherche liée

## Autres partenaires académiques
* **Université Paris II Panthéon-Assas, Université Paris Dauphine, Université Clermont Auvergne :**
    - Co-encadrement de doctorats
    - Séminaires doctoraux

Partenariats de mobilité internationale (Stage 4<sup>ième</sup> Année à l’EMINES , 2<sup>ième</sup> année cycle ingenieur) : L’école développe une forte ouverture internationale via de nombreux partenariats de mobilité : elle collabore avec des institutions en Amérique du Sud (Brésil), en Amérique centrale (Mexique), en Asie (Malaisie, Inde, Émirats arabes unis), au Moyen-Orient (Jordanie, Oman), en Afrique (Madagascar, Sénégal), ainsi qu’en Europe (Portugal, Belgique, France, Slovénie). Pour plus de détails, consulter : <u>https://www.emines-ingenieur.org/a-propos/partenariats/partenariats-universitaires</u>

## Les développements futurs :
- L’UM6P développe de nombreux partenariats avec des institutions académiques majeures, dont en particulier le MIT et Columbia University, qui bénéficiera directement l’EMINES – School of Industrial Management

# Partenariats Entreprises
## UN LIEN PRIVILÉGIÉ AVEC LE GROUPE OCP :
Les engrais sont incontournables pour répondre au défi mondial de la sécurité alimentaire. C’est pour cela qu’OCP, fort de son rôle de leader dans l’industrie des phosphates et acteur majeur des fertilisants a intensifié la diversification de ses produits et exporte aujourd’hui pas moins de 43 formules différentes répondant ainsi aux besoins spécifiques des sols et des cultures.

Le Groupe ambitionne également de faire avancer la recherche dans ce domaine, nouer des partenariats, former des spécialistes et apporter des réponses innovantes aux défis planétaires mais aussi aux enjeux auxquels est confronté le continent africain (sécurité alimentaire, développement économique, industrialisation durable, politiques publiques…). Placée au cœur de cette quête de solutions innovantes, l’Université Mohammed VI Polytechnique joue un rôle primordial dans le domaine de la recherche. C’est un pôle de recherche, de formation et d’innovation de haut niveau, dont l’ambition est d’être un pont entre le Maroc, l’Afrique et le monde.

L'UM6P bénéficie donc d’un lien stratégique fort avec l’OCP. Cela s’exprime pour l’EMINES School of Industrial Management à deux niveaux : la formation et la recherche. Au niveau de la

formation, ce lien se traduit notamment par un accès direct aux cadres et aux infrastructures de l’entreprise pour :
- Réaliser des Etudes d’Option (PFE) au sein du groupe OCP et de ses filiales ;
- Réaliser des stages ingénieur à l’international au sein des filiales internationales du groupe OCP ;
- Répondre dans le cadre d’activités pédagogiques à des problèmes identifiés par le groupe ;
- Réaliser des visites techniques, disposer d’intervenants industriel ;
- Réaliser des programmes d’executive education pour accompagner les personnels dans les évolutions du groupe OCP.

Au niveau de la recherche, ce lien se traduit par des contrats de recherche sur des problématiques qui s’inscrivent dans les axes stratégiques de l’OCP

Un partenariat plus spécifique avec la Fondation OCP permet en outre aux élèves méritants de bénéficier de bourses d’études totales ou partielles.

# PARTENARIAT AVEC RATP DEV SUR LA MOBILITÉ DU FUTUR

L’EMINES-UM6P contribue, dans une logique partenariale avec le groupe RATP Dev, à la **conception et aux développements de nouveaux services pour la mobilité du futur.**
Notamment, l’EMINES-UM6P est le partenaire historique qui a accompagné le développement du Lab d’Innovation de RATP Dev à Casablanca : CasaRoc.
En effet, de par son imbrication dans le projet de création de la nouvelle Ville Verte Mohammed VI de Ben Guérir, l’EMINES-UM6P a retenu l’axe **« Smart urban mobility »**, qui recouvre les solutions innovantes de mobilité pour les personnes et/ou les biens adaptées aux contextes locaux, comme une thématique forte de recherche et de développement au niveau local, continental et mondial.
Pour cela l’EMINES-UM6P peut s’appuyer notamment sur le développement d’une expertise en **Data Sciences**, en collaboration avec l’Ecole Polytechnique, avec pour objectif de créer de la valeur par une utilisation intelligente des données.
Par ailleurs, l’EMINES-UM6P attache une importance cruciale à l’innovation pédagogique et à la mise en œuvre de démarches pédagogiques originales. De ce fait, le partenariat avec RATP Dev nous offre un espace pour développer de nouvelles activités de formation notamment basées sur le **Learning by doing.**
A cet effet, cette démarche collaborative nous a permis de :
* Créer des formations originales (exemple du cours d’Analyses socio-économiques du numérique dont le design a porté sur la thématique de la mobilité urbaine).
* Proposer des sujets pour les projets informatiques et mécatroniques du Cycle Ingénieur.
* Proposer des attentes d’innovation aux clubs élèves de l’EMINES-UM6P au niveau robotique (club E-Tech), au niveau informatique (club E++), au niveau développement (club EJunior)...
* Conforter notre démarche de formation à l’entrepreneuriat.
* Confronter nos élèves ingénieurs aux démarches d’innovation.

# Accréditations Nationales et Internationales

Au plan national, l'EMINES – School of Industrial Management et ses formations bénéficient des éléments de reconnaissance suivants :

*   Autorisation de l’Ecole N° 404/13 du 28/11/2014
*   Autorisation de la filière Management Industriel (Cycle Préparatoire Intégré et du Cycle Ingénieur) n° 02/1528 du 03/06/2015
*   Accréditation de la filière Management Industriel (Cycle Préparatoire Intégré et du Cycle Ingénieur) n° 04/2066 du 19/10/2023
*   Partenariat Public Public (PPP) par arrêté du MESRSFC de mai 2015, qui autorise le principe de Reconnaissance par l’Etat.
*   **Reconnaissance du diplôme par l'État.** N°2.23.424 du 10/05/2023 (Équivalence aux Diplômes d'État)

# Chiffres clés de l’EMINES

**Effectifs étudiants en 2024 – 2025 : 516**
*   **Cycle préparatoire intégré : 25 % → 72 étudiants**
*   **Cycle Ingénieur : 40 % → 204 étudiants**
*   **PhD & Fellows : 5 % → 30 étudiants**
*   **Formation continue non diplômante : 3 % → 100 étudiants**
*   **Formation continue diplômante : 9 % → 110 étudiants**

**Personnel 2024-2025 :**
*   **17** Enseignants-chercheurs permanents temps plein
*   **10** Pr. affiliés temps partiel
*   **80** Enseignants vacataires et intervenants
*   **9** Ingénieurs et Cadres
*   **19** Techniciens et Agents Administratifs

# Chiffres Clés : Ingénieurs Alumni de l’EMINES au 31-12-2024

Au **31 décembre 2024**, le réseau des **ingénieurs Alumni** compte **368 diplômés** issus des promotions **2017 à 2024**. Parmi eux, **94 Alumni** exercent à l’étranger : **71 en Europe, 9 en Asie, 8 en Afrique et 6 en Amérique du Nord.**

À ce jour, **9 startups actives** ont été créées par les anciens élèves.

Concernant l’insertion professionnelle, le **salaire net moyen à la sortie** pour la promotion diplômée fin septembre 2024 est de **17 900 MAD**. Après **4 ans d’expérience** (promotions 2017 à 2020), le **salaire moyen** atteint **29 700 MAD**, et après **7 ans** (promotion 2017), il s’élève à **38 200 MAD**.

Enfin, **84 % des diplômés** sont placés dans les trois mois suivant l’obtention de leur diplôme (Ensemble des promotions 2017 à 2024) . Un an après le diplôme, plus de 98% des diplômés ont commencé́ une activité professionnelle. Ces statistiques témoignent du succès de l’Ecole, qui a su atteindre la cible entreprise qu’elle s’était fixée, dans un délai très court.

# DÉBOUCHÉS ET CARRIÈRES APRES EMINES

La formation d'ingénieurs en Management Industriel prépare les jeunes diplômés à exercer des métiers d'ingénieurs-managers dans différents secteurs d'activité, au Maroc comme à l'international.

**Nos entreprises partenaires**

Au **1er janvier 2025**, ce sont **126 entreprises et organismes**, au Maroc et à l’international, qui emploient nos diplômés. Elles couvrent les grands secteurs d’activité suivants :
*   **Production primaire** – *17 entreprises* : mines, pétrole, agribusiness, énergie
*   **Transformation secondaire** – *21 entreprises* : automobile, aéronautique, construction, technologie, pharmacie, agro-alimentaire, textile
*   **Conseil en stratégie & audit** – *15 entreprises* : conseil stratégique, audit, consulting
*   **Services techniques** – *32 entreprises* : data sciences, IA, informatique, numérique, transformation digitale, gestion de projet, optimisation
*   **Transport, logistique & distribution** – *20 entreprises* : transport, logistique, distribution
*   **Banque & finance** – *13 entreprises* : banque, finance, assurance
*   **Enseignement & recherche** – *8 organismes* : universités, centres de recherche

**Métiers de nos diplômés**

Les premiers postes occupés reflètent la diversité de la formation, couvrant un large éventail de métiers :
*   **Ingénierie** : logistique / supply chain, planification analyst, qualité, project manager, project expeditor, organisation des systèmes d’information
*   **Numérique & digital** : data scientist, transformation digitale, digital marketing, software engineer, performance analyst, financial analyst, business analyst, risk analyst
*   **Business** : marketing, business development, technico-commercial, contrôle de gestion, pricing analyst, sales, CEO de start-up
*   **Domaines généralistes** : junior consultant, ingénieur de recherche, social entrepreneurship, PhD, préparation à l’agrégation

# La direction à l’EMINES

La direction a pour mission première de concevoir la politique scientifique et pédagogique de l'École et de proposer au Conseil d’Administration de l’Université la stratégie qui permettra de la mettre en œuvre. Elle veille à préserver l'identité de l'EMINES et à garantir son excellence.

Elle est particulièrement soucieuse du développement de l'EMINES et de son ambition nationale et internationale.

Elle s’appuie directement sur les structures de concertation et de conseil internes et externes. (-> Conseils et Comités)

## NICOLAS CHEIMANOFF, DIRECTEUR

Nicolas Cheimanoff a été Directeur de l’Enseignement à MINES ParisTech de 2001 à 2013. Avant cela, il y a dirigé le Centre de Recherche en Géotechnique et en Exploitation du Sous-sol de 1990 à 2001. Il a été de plus Secrétaire Général du Centre d’Etudes des Matières Premières de 1994 à 2013 et Directeur

Délégué du site de Fontainebleau de 1999 à 2002. Professeur en Gestion des Espaces Souterrains à MINES ParisTech depuis 1995, il est diplômé de l’Ecole Polytechnique (promotion 1981) et titulaire d’un DEA (1985) et d’un Doctorat en Techniques et Economie de l’Exploitation du Sous-sol (1988). Il est impliqué dans le projet EMINES depuis juin 2010 et a la responsabilité de l’équipe projet EMINES depuis septembre 2011.

## MOHAMED BENKAMOUN, DIRECTEUR PÉDAGOGIQUE

Mohamed Benkamoun a été le Chef de Projet de l’Université Mohammed VI Polytechnique et le Vice-Président en charge des partenariats recherche de cette université. Il a été auparavant Directeur de Cabinet du PDG de l'OCP. Il avait précédemment travaillé comme conseiller au cabinet du 1er Ministre (2007 à 2009 et 1997 à 1998), comme Directeur Technique à l’Agence Nationale de Règlementation des Télécommunications (1998 à 2000), et a assuré entre 1988 et 2007 des fonctions de directions dans diverses entreprises au Maroc et en France (Télécom Global Group, Bridge Télécom Company, Meditelecom, Forbes Télécom Africa, Alcatel-Alsthom et SOCS). Il est titulaire d’un Doctorat de l’Université de Nice en Electronique et en Télécommunications (1988). Il a exercé, dans la même Université, des fonctions d’enseignant-chercheur de 1985 à 1988. Il a initié le projet EMINES dont il a constitué l’équipe à partir de juin 2010.

## NABIL MOSLEH, DIRECTEUR DE LA COOPÉRATION

Nabil Mosleh a été Directeur de la Coopération et de la Communication de l’Office National de l’Electricité et de l’Eau Potable - Branche Eau (2008 à 2014). Il y a précédemment exercé les fonctions de Chef de la Division Coopération (2003 à 2008) et de Chef du Service Relations avec les Entreprises (2002 à 2003). Il est titulaire d’un DEA en Microélectronique de l’Université Paris 7 (1992) et d’un Doctorat en Electronique de l’Université Paris Sud (1996). Il a débuté sa carrière en tant que chercheur, responsable du laboratoire d’hydrologie isotopique, au sein du Centre National de l’Energie, des Sciences et des Technique Nucléaires (1996 à 2001). Il a rejoint l’équipe projet EMINES en octobre 2014.

# # COMMENT ENTRER À L’EMINES au cycle préparatoire intégré? Postuler à emines pour intégrer le cycle préparatoire intégré ?

## ADMISSION AU CYCLE PRÉPARATOIRE INTÉGRÉ (POST-BAC)

Le cycle préparatoire intégré est ouvert aux titulaires d’un Baccalauréat scientifique désireux de réaliser une formation conduisant à un diplôme d’Ingénieur en Management Industriel. Au vu de leurs mérites et résultats académiques, les meilleurs dossiers seront retenus pour passer le concours d’admission au cycle préparatoire intégré. L’EMINES a son propre concours sous forme écrite et orale et qui essaie d’examiner surtout le potentiel du candidat et pas seulement ses acquis. Ce concours comportera :

1. Admissibilité :
   - QCM Mathématiques outils
2. Admission :
   - Oral de Mathématiques
   - Oral de Sciences Physiques
   - Oral de Raisonnement Scientifique

A l’issue des épreuves orales, une liste d’admis sera établie. L’admission sera définitive une fois les formalités administratives effectuées.

## AGENDA DE L’ADMISSION AU CYCLE PRÉPARATOIRE INTÉGRÉ :

* De janvier jusqu'au dimanche 1er juin 2025 : Dépôt <u>en ligne</u> des candidatures pour le concours d’accès au cycle préparatoire intégré via le lien suivant :

https://emines-ingenieur.org/admission/candidature-online?layout=edit

* **Jusqu'au samedi 21 juin 2025** : Dépôt <u>en ligne</u> du relevé du Bac
* Du 1er au 9 Juillet 2025 : Epreuves d’admissibilité et d'admission à Ben Guerir
* Mi-Juillet 2025 : Résultats de l’admission

# COMMENT ENTRER À L’EMINES au cycle ingénieur ?
Postuler à emines pour intégrer le cycle ingenieur ?

**ADMISSION AU NIVEAU BAC + 2 APRÈS CLASSE PRÉPARATOIRE SCIENTIFIQUE**
* Niveau de formation requis : Bac + 2 après 2 années de classes préparatoires scientifiques
* Spécialité requise : Options MP, PSI ou TSI
* Mode de sélection : présélection sur dossier, en fonction des résultats scolaires de Prépa. Sélection sur épreuves comportant les éléments suivants :
1. Admissibilité :
- QCM Mathématiques outils
2. Admission :
- Oral de Mathématiques
- Oral de Sciences Physiques
- Oral de Raisonnement Scientifique

**ADMISSION AU NIVEAU BAC + 3 APRÈS LICENCE SCIENTIFIQUE**
* Niveau de formation requis : Bac + 3 après Licence d'Etudes Fondamentales
* Spécialité requise : Mathématiques Pures, ou Mathématiques et Informatique, ou Mathématiques et Applications, ou Mathématiques Appliquées, ou Science de la Matière Physique, ou équivalents étrangers
* Mode de sélection : pré-admissibilité sur dossier, en fonction des résultats scolaires de Licence. Sélection sur épreuves comportant les éléments suivants :
1. Admissibilité :
- QCM Mathématiques outils 2. Admission :
- Oral de Mathématiques
- Oral de Sciences Physiques
- Oral de Raisonnement Scientifique

**AGENDA DE L’ADMISSION AU CYCLE INGÉNIEUR (POST-PRÉPAS)**
* **De janvier jusqu'au dimanche 11 mai 2025** : Dépôt <u>en ligne</u> des candidatures pour le concours d’accès au cycle Ingénieur via le lien :
https://emines-ingenieur.org/admission/candidature-online?layout=edit
* Du 26 mai au 4 juin 2025 : Epreuves d'admissibilité et d’admission à Ben Guerir • Mi-Juin 2025 : Résultats de l’admission

# Quelles sont les filières qui existent à L’EMINES ? C’est quoi une école d’ingénieur généraliste ?

Il y a une seule filière généraliste à l’EMINES appelée management industriel. C’est une école qui forme des ingénieurs généralistes, Ce sont des ingénieurs qui maîtrisent les savoirs et savoir-faire scientifiques et techniques de base mais qui ont en même temps des compétences en tout ce qui est économie et management. C’est un cursus original et très diversifié qui donne aux élèves la chance d’explorer différents domaines et donc de savoir ce qu’ils ont vraiment envie de faire par la suite, il leur permet aussi de développer leur capacité d’apprentissage (apprendre à apprendre) grâce à la variété de matières et de projets qu’ils réalisent pendant leur cursus. A noter que chacun fait environ 20 projets pour la plupart collectifs en cycle ingénieur.

Pour avoir la liste de tous les cours, les projets et les stages du cursus de l’EMINES avec les profs qui s’en occupent, vous pouvez consulter le site internet de l’EMINES :
<u>https://www.emines-ingenieur.org/a-propos/enseignants</u>
<u>https://www.emines-ingenieur.org/formation/formation-ingenieur</u>

# Le cycle Préparatoire Intégré de l’EMINES ?

Le Cycle Préparatoire Intégré a pour objectif principal de préparer les étudiants au Cycle Ingénieur de l’EMINES. Le cahier des charges du Cycle Préparatoire Intégré peut ainsi être formulé comme suit : Une vraie classe préparatoire scientifique, en ce sens qu’elle est constituée de 2 années intensives qui :
- Doivent permettre l’acquisition des fondamentaux en mathématiques, informatique, physique classique, sciences de l’ingénieur et en langues, sur la base du programme de MPSI/MP*,
- Doivent apprendre aux étudiants à gérer une quantité de travail telle qu’il leur faudra obligatoirement trouver des méthodes d’organisation qui leur sont adaptées,
- Doivent aussi leur apprendre à gérer une quantité de nouvelles connaissances telle qu’ils ne pourront pas se servir du « par cœur » mais devront trouver en eux-mêmes des méthodes de classement de l’information.
- Mais aussi une classe préparatoire intégrée, c’est-à-dire qui permet de commencer à traiter des sujets réels, et à les mettre en œuvre pratiquement au travers des différents projets du cycle (projets informatique, projet d’ingénierie (conception et fabrication de robots), physique expérimentale, français, anglais), afin d’accéder directement au Cycle Ingénieur en cas de validation de tous les modules.

# Le programme du cycle Ingénieur de l’EMINES ?

L’EMINES forme des ingénieurs généralistes à large spectre capables d’approfondissement tant que de besoin, Elle met sur le marché :
- Des diplômés familiarisés avec l’international, ce qui a conduit l’École à rendre obligatoire et à financer une mobilité à l’étranger pour tous ;
- Des diplômés capables d’écoute, dotés de qualités humaines et relationnelles, capables de travailler collectivement, ce qui a conduit L’École à multiplier les projets de groupe ;
- Des diplômés capables de prises de risque, d’analyse critique, disposant de qualités entrepreneuriales, ce qui a conduit l’École à développer la méthode pédagogique du « Learning by Doing », à mettre en place en tronc commun un Acte d’Entreprendre, et à créer un programme d’accompagnement des start-up ;

- Des diplômés maitrisant le digital, ce qui a conduit l’École à mettre un poids très important sur les modules liés à la discipline informatique ;
- Enfin des diplômés familiarisés avec la pratique et les réalités du terrain, aptes à travailler immédiatement, ce qui a conduit l’École à placer les stages dans le cursus et à choisir d’orienter la majorité des projets vers des cas pratiques.

# Est-ce-que l’EMINES a un double-diplôme ?

Non, l’EMINES n’a pas de double-diplôme. Les diplômés peuvent faire un diplôme complémentaire après la fin de la formation mais ils ne peuvent pas faire un autre diplôme en même temps que celui de l’EMINES. C’est un choix délibéré : l’École ne veut pas être choisie pour donner le diplôme d’un autre. Il faut noter que les établissements prestigieux en France, aux États-Unis ou ailleurs, n’ont pas de double-diplôme, parce que tout simplement ils n’ont pas besoin de renforcer leur diplôme par un autre, c’est aussi le cas de l’EMINES.

En revanche, 100% des élèves de l’EMINES sont amenés à faire un stage de 3 à 4 mois à l’étranger (Amérique Latine, Asie, Afrique, Europe, à la fin de la deuxième année du cycle ingénieur, le stage peut être dans des entreprises ou des universités et l’École se charge de trouver les stages à tous les élèves et les aide financièrement pour couvrir leurs charges.

# Est-ce-que L’EMINES accompagnent ses élèves dans la recherche et préparation à l’emploi ?

L’emploi constitue le principal critère de performance qui permet d’évaluer la qualité de l’Ecole et de ses formations.
L’Ecole a intégré à l’emploi du temps de dernière année un cycle de préparation à l’emploi, qui permet aux futurs diplômés de s’initier à la rédaction de CV, aux tests qualitatifs et quantitatifs de recrutement, et aux entretiens d’embauche. Un service stages et emploi est par ailleurs en lien permanent avec les entreprises partenaires et peut ainsi proposer à chaque futur diplômés de nombreuses offres d’emploi.

# Formations complémentaires suivies par les diplômés de l’EMINES :

Certains diplômés peuvent être intéressés par des formations complémentaires ( Master spécialisé, doctorat, MBA etc…), que ce soit juste après l’Ecole ou plus tard dans leur carrière. Toutes ces formations sont réalisées à l’étranger, dans des établissements très sélectifs.

**PhD – 36 personnes**
* Mathématiques appliquées (15)
* Data Sciences (12)
* Mathématiques (4)
* Environnement (2)
* Physique (2)
* Intelligence collective (1)

(Qlq Exemples Institutions : UM6P, Université Clermont Auvergne, Université Paris 6 Sorbonne, Université Paris Nanterre, Université de Rennes 1, PSL, Mines Paris, KTH, NUS, etc.)

**Master 2 & M.Sc. & M.S. – 50 personnes**
* M2 Data Sciences – X (25)
* M2 Finances – X (3)
* M2 Business / Finance – ESSEC (5)
* M2 & MSc – France (Divers) (5)
* MSc. et MBA – Grande-Bretagne & États-Unis (Divers) (8)

* Mastères Spécialisés (4)
(Qlq Exemples Institutions: UM6P, Université Paris-Saclay, ESSEC, ESCP, Université Paris Dauphine – PSL, Coventry University, Oxford Brookes University, University at Buffalo, University of Dundee, Hult, École des Ponts, etc.)

# Emines contact
contact@eminesingenieur.org
www.emines-ingenieur.org

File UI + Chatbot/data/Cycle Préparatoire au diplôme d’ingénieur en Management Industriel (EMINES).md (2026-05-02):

# EMINES
School of Industrial Management

## Cycle Préparatoire Intégré / Cycle Ingénieur

The central portion of the page features a large photograph of a modern building. The structure is made of a reddish-brown, textured material and has a large, deep rectangular recess that houses a multi-paned glass window. This window reflects a clear blue sky with wispy white clouds. At the base of the window, a dark entrance with several doors is visible. The photograph is partially overlaid with stylized geometric patterns: white linear designs on the lower left and dark blue linear designs along the right edge of the page.

**U M 6 P**
University Mohammed VI Polytechnic

# Un Ingénieur en Management Industriel durable au service de l’Afrique

A signing ceremony with several people seated at a long table covered with a red cloth. Sa Majesté le Roi Mohammed VI is present.
Signature de la Convention Université Mohammed VI Polytechnique entre OCP et le Ministère de l’Enseignement Supérieur, en présence de Sa Majesté le Roi Mohammed VI.

> (...) La réforme du système d’éducation se doit non seulement d’assurer l’accès égal et équitable à l’école et à l’université pour tous nos enfants, mais également de leur garantir le droit à un enseignement de qualité, doté d’une forte attractivité et adapté à la vie qui les attend (...)
>
> Discours de Sa Majesté le Roi Mohammed VI, à l’occasion de la dernière commémoration de la Révolution du Roi et du Peuple 20 août 2012.

Sa Majesté le Roi Mohammed VI interacting with students and staff in a laboratory or workshop setting.
Sa Majesté le Roi Mohammed VI a procédé jeudi 12/01/2017 à l’inauguration de l’Université Mohammed VI Polytechnique.

A large, modern, orange-colored building with many windows, part of the UM6P campus.

**L’Afrique est une multitude.** Cet immense continent, berceau de l’humanité, comptant cinquante-quatre états, deux mille langues, mille groupes ethniques, trente millions de kilomètres carrés et une population qui devrait doubler d’ici 2050, est un **espace complexe**, qui doit faire face à des défis majeurs pour consolider sa propre dynamique de développement.

La **révolution numérique** actuelle qui transforme les chaînes de valeur au niveau mondial et le développement des compétences est un de ces défis.

Pour l’Afrique, c’est l’opportunité d’être créatrice **de valeur** dans les industries traditionnelles telles que le secteur manufacturier, mais également dans d’autres secteurs et activités essentiels au développement industriel tels que la logistique, l’agriculture, l’énergie, les communications, les services, la croissance verte et les villes intelligentes.

Le continent africain, fort de son histoire et de son potentiel, dispose d’un ensemble d’atouts majeurs pour inventer son **propre modèle d’industrialisation durable.**

Pour cela, ce continent doit transformer ses modèles d’éducation afin de former les talents qui contribueront à écrire cet avenir. Il doit notamment pouvoir s’appuyer sur des **ingénieurs de haut niveau scientifique, inventifs, créatifs et entrepreneurs** qui sauront conduire le progrès en Afrique.

**L’EMINES - School of Industrial Management a pour vocation de former ces ingénieurs.**
Le profil des ingénieurs de l’EMINES découle logiquement de cette vocation :

```mermaid
graph TD
    Center((PROFIL DE<br/>L'INGENIEUR<br/>DE L'EMINES))
    Center --- DIGITAL
    Center --- ENTREPRENEUR
    Center --- MANAGER
    Center --- SCIENTIFIQUE
    Center --- INTERCULTUREL
```

Au sein de **l’Université Mohammed 6 Polytechnique (UM6P)**, l’EMINES met ainsi en œuvre deux principes fondateurs de cette université: le **développement des talents au service de l’Afrique** et une pédagogie originale basée sur le **learning by doing**.

**L’EMINES offre ainsi à ses élèves-ingénieurs une formation fondamentale scientifique, technique et socio-économique, marquée par l’excellence académique, appuyée sur un fort développement de savoir-faire pratique et de savoir-être.**

www.emines-ingenieur.org 3

# Une formation d’Ingénieur au service de l’industrialisation durable de l’Afrique ...

## Cycle Préparatoire Intégré 120 ECTS (4 semestres de 30 ECTS – 2 ans)

Les quatre semestres de formation du Cycle Préparatoire Intégré de l’EMINES ont pour objectif d’accroître significativement le niveau des connaissances des bacheliers dans différents champs disciplinaires de manière à les rendre aptes à suivre le Cycle Ingénieur.

### Répartition du volume horaire par matière

<table>
  <tbody>
    <tr>
        <td>Matière</td>
        <td>Pourcentage</td>
    </tr>
    <tr>
        <td>Mathématiques</td>
        <td>23%</td>
    </tr>
    <tr>
        <td>Projet d'Ingénierie</td>
        <td>19%</td>
    </tr>
    <tr>
        <td>Physique Classique</td>
        <td>16%</td>
    </tr>
    <tr>
        <td>Physique Expérimentale</td>
        <td>13%</td>
    </tr>
    <tr>
        <td>Anglais</td>
        <td>10%</td>
    </tr>
    <tr>
        <td>Français</td>
        <td>10%</td>
    </tr>
    <tr>
        <td>Informatique</td>
        <td>6%</td>
    </tr>
    <tr>
        <td>Sport</td>
        <td>3%</td>
    </tr>
  </tbody>
</table>

## Cycle Ingénieur 180 ECTS (6 semestres de 30 ECTS – 3 ans)

La progression pédagogique du Cycle Ingénieur est construite de manière à permettre à chaque élève ingénieur d’acquérir les différentes compétences attendues d’un diplômé de l’EMINES.

<table>
  <thead>
    <tr>
        <th></th>
        <th>Première année</th>
        <th>Deuxième année</th>
        <th>Troisième année</th>
    </tr>
  </thead>
  <tbody>
    <tr>
        <td>SCIENTIFIQUE</td>
        <td>* Calcul Différentiel<br/>* Calcul Intégral<br/>* Economie Générale<br/>* Mécanique<br/>* Chimie Industrielle<br/>* Thermodynamique Industrielle</td>
        <td>* Probabilités<br/>* Statistiques<br/>* Data Science*, Mécanique des fluides*, Nanotechnologies*, Cosmologie*, Energie renouvelable*</td>
        <td>* Développement Durable<br/>* Etude d'Option (PFE)</td>
    </tr>
    <tr>
        <td>MANAGER</td>
        <td>* Stage d'observation en Géologie<br/>* Recherche Opérationnelle<br/>* Biomedical engineering<br/>* Module d'Initiation au Management Industriel<br/>* Description de Controverses</td>
        <td>* Systèmes de Production et Logistique<br/>* Evaluation des coûts<br/>* Mécatronique<br/>* Stratégie minière<br/>* Management hospitalier*</td>
        <td>* Stratégie d'entreprise<br/>* Droit / Comptabilité / GRH / Achats / Finance d'entreprise<br/>* Lean Management<br/>* Maintenance industrielle 4.0<br/>* Etude d'Option (PFE)</td>
    </tr>
    <tr>
        <td>DIGITAL</td>
        <td>* Python, Java, SQL, HTML/PHP</td>
        <td>* Analytic Edge<br/>* Automatique<br/>* Mécatronique<br/>* Cryptographie*, Cyber sécurité*<br/>* VBA</td>
        <td>* Sureté de fonctionnement*<br/>* ERP / SAP®<br/>* Etude d'Option (PFE)</td>
    </tr>
    <tr>
        <td>ENTREPRENEUR</td>
        <td>* Acte d'Entreprendre I<br/>* Entrepreneurship week</td>
        <td>* Gestion de projet*, Réseaux socio-numériques*, Acte d'Entreprendre II*<br/>* Année de césure</td>
        <td>* Business Game<br/>* Etude d'Option (PFE)</td>
    </tr>
    <tr>
        <td>INTERCULTUREL</td>
        <td>* Anglais<br/>* LV2 (Mandarin / Espagnol)<br/>* Sport<br/>* Stage d'exécution</td>
        <td>* Anglais<br/>* LV2 (Mandarin / Espagnol)<br/>* Sport<br/>* Shadowing<br/>* Mobilité à l'international</td>
        <td>* Développement personnel par le théâtre<br/>* Intelligence collective<br/>* Préparation à la vie professionnelle<br/>* Préparation au TOEIC<br/>* Etude d'Option (PFE)</td>
    </tr>
  </tbody>
</table>

**Légende :**
*   <mark style="background-color: #76b82d; color: white;"> Le terrain </mark>
*   <mark style="background-color: #005596; color: white;"> Les cours </mark>
*   <mark style="background-color: #e30613; color: white;"> Les projets </mark>
*   <mark style="background-color: #f39200; color: white;"> Learning by doing </mark>
*   \*: Cours au choix

L’Option va permettre à chaque élève ingénieur de mettre en oeuvre les compétences acquises durant son cursus dans un domaine de son choix, sans pour autant préjuger d’une orientation professionnelle définitive.

L’étude d’option clôture la scolarité et atteste de la compétence d’un élève ingénieur à savoir modéliser un problème complexe en contexte réel et à y apporter une solution innovante avec une mise en oeuvre concrète dans l’entreprise d’accueil.

### Contenu des Options

<table>
  <thead>
    <tr>
        <th>OPTION SUPPLY CHAIN MANAGEMENT</th>
        <th>Contenu</th>
    </tr>
  </thead>
  <tbody>
    <tr>
        <td>Responsable :<br/>**Frédéric FONTANE**<br/>(Directeur Adjoint Mines ParisTech)</td>
        <td>Semaine 1 : Enjeux industriels et logistiques<br/>Semaine 2 : Planification industrielle et gestion de projet<br/>Semaine 3 : Maintenance et Qualité<br/>Semaine 4 : Prévision des ventes et gestion de stock<br/>Semaine 5 : Chaine logistique<br/>Semaine 6 : Modeleur et Problem design<br/>Semaine 7 : Simulation à événements discrets<br/>Semaine 8 : Visites industrielles</td>
    </tr>
  </tbody>
</table>
<table>
  <thead>
    <tr>
        <th>OPTION MINING</th>
        <th>Contenu</th>
    </tr>
  </thead>
  <tbody>
    <tr>
        <td>Responsables :<br/>**Damien GOETZ**<br/>(Pr. Mines ParisTech)<br/>**Ismail AKALAY**<br/>(DG. SONASID)</td>
        <td>Semaine 1 : Projets miniers : de la géologie à l'exploitation<br/>Semaine 2 : Planification minière<br/>Semaine 3 : Mécanique des roches, stabilité et soutènement<br/>Semaine 4 : Méthodes de traitement et impacts environnementaux<br/>Semaine 5 : Processus achats-logistique-marketing et RSE<br/>Semaine 6 : Economie et sélectivité<br/>Semaine 7 : Visites industrielles 1<br/>Semaine 8 : Visites industrielles 2</td>
    </tr>
  </tbody>
</table>
<table>
  <thead>
    <tr>
        <th>OPTION DATA SCIENCES INDUSTRIELLES</th>
        <th>Contenu</th>
    </tr>
  </thead>
  <tbody>
    <tr>
        <td>Responsables :<br/>**Eric MOULINES**<br/>(Pr. Ecole Polytechnique)<br/>**Geneviève ROBIN**<br/>(Dr. CNRS)</td>
        <td>Semaine 1 : Approfondissement en statistiques, régression linéaire et modèles linéaires généralisés<br/>Semaine 2 : Introduction à l'apprentissage supervisé : Arbres de classification et de régression, forêts aléatoires, méthodes ensemblistes, boosting<br/>Semaine 3 : Apprentissage non-supervisé : ACP, analyse factorielle, classification hiérarchique, algorithme EM<br/>Semaine 4 : Introduction à l'apprentissage profond<br/>Semaine 5 : Machines à vecteurs de support et méthodes à noyaux<br/>Semaine 6 : Introduction au traitement des langues naturelles<br/>Semaine 7 : Data Analytics pour les processus industriels<br/>Semaine 8 : Datacamp</td>
    </tr>
  </tbody>
</table>
<table>
  <thead>
    <tr>
        <th>OPTION MANAGEMENT DES ENTREPRISES INNOVANTES</th>
        <th>Contenu</th>
    </tr>
  </thead>
  <tbody>
    <tr>
        <td>Responsables :<br/>**Michel BERRY**<br/>(Ecole de Paris du Management)<br/>**Christophe DESHAYES**<br/>(Ecole de Paris du Management)</td>
        <td>Semaine 1 : Introduction au management, aux outils de gestion, aux technologies invisibles et aux modes managériales (Prise de recul)<br/>Semaine 2 : Management de l'innovation<br/>Semaine 3 : Gestion de projets complexes et innovants<br/>Semaine 4 : Entrepreneuriat – Entrepreneuriat social - Intrapreneuriat<br/>Semaine 5 : Transformation numérique et logique de plateforme<br/>Semaine 6 : Transition écologique et financement<br/>Semaine 7 : Libération des énergies – Management de proximité<br/>Semaine 8 : Gestion de l'extrême</td>
    </tr>
  </tbody>
</table>

4    www.emines-ingenieur.org    www.emines-ingenieur.org    5

... bénéficiant d’une pédagogie par projet en lien étroit avec le monde industriel ...

# Les projets

* **Cycle préparatoire intégré**
    * Projet d’Ingénierie « construction de robots »
    * Projet de Physique expérimentale

* **1<sup>ère</sup> année du cycle ingénieur**
    * Initiation au Management Industriel (par groupe de 10)
    * Acte d’Entreprendre (individuel ou en groupe)
    * Controverse (par groupe de 5)
    * Informatique (Client réel)
    * Mini-projet d’entrepreneuriat
    * Mini-projet de mécanique
    * Mini-projet d’économie

* **2<sup>ème</sup> année du cycle ingénieur**
    * Projet mécatronique (par groupe de 10)
    * Projet de statistiques (par groupe de 3)
    * Mini-projet d’automatique

* **3<sup>ème</sup> année du cycle ingénieur**
    * Jeu d’entreprise
    * Projets d’option (selon l’option choisie)

# Immersion terrain

* **1<sup>ère</sup> année du Cycle Ingénieur**
    * Stage ouvrier (4 semaines en entreprise)
    * Visites industrielles d’Initiation au Management Industriel (1 semaine de visites)
    * Stage d’observation en géologie (1 semaine de terrain)

* **2<sup>ème</sup> année du cycle ingénieur**
    * Stage de shadowing (1 semaine en entreprise)
    * Mobilité à l’international d’initiation à la recherche (12 à 16 semaines en laboratoire académique ou industriel à l’étranger)

* **3<sup>ème</sup> année du cycle ingénieur**
    * Visites industrielles d’option (1 à 3 semaines de terrain selon l’option choisie)
    * Etude d’option (24 semaines en entreprise + 1 semaine de restitution)

# Les liens avec le monde de la recherche

* Stage de 12 à 16 semaines dans une université ou un laboratoire de recherche industrielle à l’étranger (entre la 2ème et la 3ème année du cycle ingénieur)
* Projets immergés dans les laboratoires de recherche OCP Africa ORANO OCP de l’Ecole et de l’UM6P, et/ou en lien avec les plates-formes technologiques de l’UM6P, Green Energy Park, Green Building Park, Ferme Expérimentale
* Majorité des enseignants issus du monde de la recherche académique ou industrielle

> * **Au moins 42 semaines** de terrain, principalement en entreprise, pour tous les élèves
> * **dont minimum 3 mois** à l’étranger pour tous les élèves
> * **forte implication industrielle** assurant ainsi une réelle actualité des enseignements.

# Mobilité à l’international en 2<sup>ème</sup> année ingénieur

L'image montre une carte du monde avec plusieurs points verts localisant les destinations de mobilité internationale en Amérique du Nord, en Europe, en Afrique et en Asie.

# Exemples d’étude d’option

<table>
  <thead>
    <tr>
        <th>Option<br/>Supply Chain Management</th>
        <th>Option<br/>Supply Chain Management</th>
        <th>Option Data Sciences<br/>Industrielles</th>
    </tr>
  </thead>
  <tbody>
    <tr>
        <td>JAQIR SOUFIANE<br/>Promotion 2019<br/><br/>ISMAIL AIT OUAHMANE<br/>Promotion 2019</td>
        <td>OUMAIMA FASLI<br/>Promotion 2019</td>
        <td>YOUSSEF FAOUZI<br/>Promotion 2021</td>
    </tr>
    <tr>
        <td>**Nouvelle stratégies pour améliorer la supply chain des fertilisants en Ethiopie**</td>
        <td>**Planification de la phase finale de l’exploitation de la mine de Cominak**</td>
        <td>**Modélisation et implémentation d’une solution de prédiction du taux de perte pour la clientèle Particuliers Résident**</td>
    </tr>
    <tr>
        <td>**OCP Africa**</td>
        <td>**ORANO**</td>
        <td>**BCP**</td>
    </tr>
    <tr>
        <td>Elaboration de schémas directeurs logistiques pour approvisionner en engrais les agriculteurs éthiopiens et comparaison de ces scénarios en fonction du coût, de la disponibilité produits et de l’empreinte environnementale.</td>
        <td>Détermination des conditions pour exploiter des stots riches en uranium en réalisant, d’une part, une étude géotechnique pour caractériser les conditions géométriques et géo-mécaniques de leur exploitation, et, d’autre part, une définition de l’organisation pour planifier cette extraction.</td>
        <td>Développement d’un outil de prédiction du taux de perte de la clientèle en utilisant des données, issues du datawarehouse de la banque, concernant les informations des clients et l’historique de leurs opérations bancaires.</td>
    </tr>
  </tbody>
</table>

6    www.emines-ingenieur.org    www.emines-ingenieur.org    7

... dans une Ecole ouverte sur le monde ...

A photograph of a young man looking through a glass surface with mathematical or scientific notations written on it.

## Les langues

*   L'apprentissage des langues s'appuie sur le Language Lab de l'UM6P. Ce dernier mobilise des méthodes pédagogiques originales et variées (théâtre, debating, Model United Nations, ...).
*   Anglais, outil de travail pour tous.
*   Français en cycle préparatoire intégré.
*   Chinois ou Espagnol au choix dans le cycle ingénieur.

## L'étranger

*   La mobilité de fin de 2ème année est volontairement orienté vers les pays à forte croissance, avenir du développement mondial et futurs partenaires économiques majeurs du Maroc : Brésil, Singapour, Mexique, Chine, Malaisie ...
*   Voyages d'option (pour certaines options) à l'étranger.

## Partenariat privilégié avec l'Ecole des Mines de Paris

*   Nombreux enseignants issus de l'Ecole des Mines de Paris.
*   Supports pédagogiques communs.
*   Activités de recherche liées.
*   Encadrement d'option.

## Autres partenaires universitaires

*   Partenariat de recherche et d'enseignement avec plusieurs enseignants de l'Ecole Polytechnique et du MIT.
*   Partenaires divers en Amérique Latine et Asie du Sud-Est pour la mobilité internationale.

## Recherche orientée vers l'industrie

*   PhD « industriel » : réalisation d'une thèse sur une problématique de recherche en management industriel d'une entreprise, encadrée par un professeur de l'EMINES.
*   Encadrement de recherche : recours à l'expertise des professeurs internationaux affiliés à l'EMINES sur la gestion industrielle et logistique, l'économie des matières premières, les data sciences et la modélisation.

8    www.emines-ingenieur.org    www.emines-ingenieur.org    9

... au cœur de l’UM6P ...

# Université Mohammed VI Polytechnique

L’UM6P est une open university, au service de la recherche et de l’éducation pour l’Afrique. Elle a pour objectif de

## DÉFIS AFRICAINS

*   Gestion rationnelle des ressources naturelles
*   Développement du Capital Humain
*   Industrialisation durable
*   Politiques publiques agiles

## SUJETS DE RECHERCHE

*   Water, Agriculture & Environment
*   Natural Resources & Food Security
*   Renewable Energy
*   Industrial & Chemical Engineering
*   Biotechnology & Biomedical Engineering
*   Architecture, Urban Planning & Land Use
*   Geology and Sustainable mining
*   Agricultural Economics & Development
*   Chemical and Bio-chemical / Green Process Engineering
*   Complex system engineering and Human Sciences
*   Behavioral Sciences
*   Computer & Communication Scientist
*   Medical Application Interfae
*   Industrial Economy and emerging Africa

Cette université de nouvelle génération se situe au coeur de la **Ville Verte Mohammed VI**, qui est un projet modèle d’inovation urbaine conçu autour du savoir, de l’inovation et de la durabilité.

Chiffres projetés :

<table>
  <tbody>
    <tr>
        <td>1000 Ha<br/>(Map icon)</td>
        <td>100.000<br/>Inhabitants</td>
        <td>25.000<br/>Residential units</td>
        <td>80 Ha<br/>Green Promenade</td>
    </tr>
    <tr>
        <td>20 m²<br/>Green spaces per inhabitant</td>
        <td>50 Ha<br/>Tertiary</td>
        <td>6.000<br/>Students &amp; researchers</td>
        <td>200.000 m²<br/>GLA of commerce</td>
    </tr>
  </tbody>
</table>

The image shows a wide-angle view of a modern university building courtyard with a large, white, geometric canopy structure. Students are seen walking and sitting in the open area, which features orange bean bags and modern architectural elements.

## LES CONDITIONS DE VIE

The image shows a group of seven students lying on green grass in a circle, their heads towards the center, looking up and smiling at the camera.

*   Frais de scolarité et de logement – visitez notre site internet www.emines-ingenieur.org
*   Possibilité de **Bourses d’Excellence** couvrant totalement ou partiellement les frais de scolarité.
*   Possibilité de **Bourses de Vie** sous conditions de ressources couvrant totalement ou partiellement les frais de scolarité, de logement et de nourriture.

## Vie associative

*   Bureau Des Elèves
*   Bureau Des Sports
*   Bureau Des Arts (Musique, Danse, Théâtre, Dessin, Photo et Vidéo)
*   EMINES Technology (E-Tech, EMINES Solar Car, E-Social Entrepreneurship)
*   E-Solidarity (E-Olives, Caravane du sourire, Soutien scolaire)
*   E-Junior Entreprise, Great debaters, MUN, E-Astro, …

## Hébergement et restauration

*   Les résidences étudiantes affectée à l’EMINES comptent 300 chambres
*   Cafétéria et restaurant universitaires.

## Le sport

*   Les installations sportives de l’UM6P ont été particulièrement soignées. Ainsi, une piscine couverte, 6 terrains multisport, une salle de musculation et une salle de cardio ont été construits.
*   L’école est également membre du Cartel des Mines, association réunissant une fois par an les étudiants sportifs des Ecoles des Mines françaises, espagnoles, allemandes, italiennes, anglaises et russes.
*   Enfin, l’ecole participe aux différentes compétitions et tournois universitaires Marocains.

## Accessibilité et transports

The image shows a student sitting on a bed in a modern dormitory room, looking at a smartphone. The room has a desk with a laptop and a window.

*   Ben Guerir se situe à 1 heure de Marrakech et bénéficie ainsi de la proximité avec cette grande ville et les autres universités qui s’y trouvent.
*   De plus, l’EMINES est facilement accessible par autoroute et par train. Les aéroports de Marrakech et Casablanca se trouvent aussi à proximité.

10 www.emines-ingenieur.org
www.emines-ingenieur.org 11

... permettant une vie étudiante de qualité et des perspectives d’avenir.

The page features a large aerial view of the University Mohammed VI Polytechnic campus, showing modern buildings, green spaces, and various facilities. Key locations are labeled:

*   UNIVERSITY MOHAMMED VI POLYTECHNIC
*   Station M
*   Green & SMART Building Park
*   Datacenter
*   Teleport
*   Green Energy Park

Below the main image are two smaller photographs:
*   On the left, a group of students is seen walking along a tree-lined path on campus.
*   On the right, students are shown in a modern, well-lit indoor common area or lounge, engaged in conversation and study.

# Témoignages de lauréats (Que retiens-tu de ton parcours à l’EMINES ?)

[Portrait of Wassila BOUGUEJJA]
> « Tout sauf monotone ! J’en ressors armée par des compétences fondamentales, grandie car entourée et formée par des personnes aussi compétentes qu’humbles et ouverte à toute sorte d’expériences ! A défaut d’avoir développé une expertise précise, on m’a permis d’avoir une vision complète du monde professionnel de demain et d’être aux aguets des nouvelles innovations »
**Wassila BOUGUEJJA** – 1er Poste : Consultante en stratégie, BCG, Casablanca, Maroc

[Portrait of Mehdi CHERGUI]
> « Un parcours très riche, mais surtout unique. Car durant ces quelques années, EMINES et moi, nous avons grandi ensemble ! J’ai eu l’opportunité de développer mes compétences techniques mais surtout mes soft skills ce qui est essentiel dans la réussite des missions professionnelles que je mène actuellement »
**Mehdi CHERGUI** – 1er Poste : Chef de projet d’excellence opérationnelle & amélioration continue, TOTAL, Dakar, Sénégal

[Portrait of Carl Josué TALI ATOUNDOU]
> « À mon arrivée à l’EMINES, au Maroc, je ne m’attendais pas à kiffer autant ma vie universitaire. De par sa formation qui cible l’ingénieur, le manager, mais aussi l’humain, l’école m’a permis de découvrir une meilleure version de moi-même. Pendant ces 5 années, j’ai évolué dans un environnement qui m’a permis d’exploiter au mieux mes talents dans différentes disciplines d’enseignement (projet d’ingénierie, informatique, mécatronique, physique expérimentale, ...) parmi lesquels je me suis découvert une passion pour l’entrepreneuriat.
>
> Cette passion naissante fut d’ailleurs l’objet de mon projet de fin d’études. En effet, ce dernier consistait à réaliser une étude de préfaisabilité de la création d’une entreprise technologique pour une solution de réfrigération sans électricité et sans eau. Avec 3 de mes camarades de promotion, nous avons passé 6 mois de travail acharné sur ce projet dont les résultats nous ont permis d’obtenir un financement de la part de l’UM6P afin de créer notre startup : BMTA & C.
>
> Aujourd’hui encore, je vis cette passion chaque jour en travaillant comme entrepreneur sur notre projet de réfrigération sans électricité et sans eau, avec pour objectif d’impacter l’Afrique, plus généralement le monde, à travers l’innovation »
**Carl Josué TALI ATOUNDOU** – 1er Poste : Co créateur de la start up BMTA & C, Ben Guérir, Maroc

[Portrait of Latifa BOUSSAADI]
> « Les trois années que j’ai passées à l’EMINES ont été sans doute très riches en matière d’apprentissage sur tous les niveaux : sciences dures (maths, physiques), programmation, recherche opérationnelle, gestion projets et communication. J’ai eu la chance d’avoir des cours très variés, et cette diversité m’a surtout permis de me développer et d’être suffisamment outillée pour s’adapter rapidement à n’importe quelle situation qui peut se présenter dans mon quotidien professionnel. L’ensemble de ces compétences me sont fort utiles pour conduire les missions de mon équipe au sein du département Supply Chain & Performance du site Jorf Lasfar du groupe OCP. Comme nous devons assurer une optimisation globale et continue des activités du site en se coordonnant avec les entités corporate, le commercial et le Business Steering, la flexibilité, la rigueur, la proactivité et l’agilité sont des capacités essentielles que j’ai acquises à l’EMINES »
**Latifa BOUSSAADI** – 1er Poste : Supply Chain Planning Engineer, OCP, El Jadida, Maroc

<page_footer>
www.emines-ingenieur.org    13
</page_footer>

12    www.emines-ingenieur.org

Les objectifs de l'EMINES en chiffres

# EFFECTIFS VISÉS

*   **35 élèves** par promotion (en 1<sup>ère</sup> et 2<sup>ème</sup> années du cycle préparatoire intégré)
*   **70 élèves** par promotion (en 1<sup>ère</sup>, 2<sup>ème</sup> et 3<sup>ème</sup> années du cycle ingénieur)

---

# COMMENT ENTRER À L'EMINES ?
www.emines-ingenieur.org

*   **En cycle préparatoire intégré**
    *   Admission sur concours EMINES
        - Elèves titulaires du Baccalauréat Scientifique - 35 places

*   **En cycle ingénieur**
    *   Admission sur concours EMINES
        - Elèves de classes préparatoires scientifiques (MP, PSI, TSI), ou équivalent étranger - 35 places

The image shows a group of five students walking and talking in a modern, brightly lit university hallway. On the left wall, there is a large digital screen displaying a building and the time "Mardi 17 16:32". The students are dressed in casual attire, carrying books and folders.

14    www.emines-ingenieur.org    www.emines-ingenieur.org    15

# EMINES
## School of Industrial Management

### UNIVERSITÉ MOHAMMED VI POLYTECHNIQUE

contact@emines-ingenieur.org
www.emines-ingenieur.org

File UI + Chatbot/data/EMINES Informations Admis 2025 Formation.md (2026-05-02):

EMINES
School of Industrial Management
UNIVERSITÉ MOHAMMED VI POLYTECHNIQUE

# Formation Ingénieur

## EMINES – School of Industrial Management

### Eléments d’information

-

#### Juin 2025

UM6P
University Mohammed VI Polytechnic

EMINES – Informations Admis – Juin 2025

# LES ATOUTS DE L’EMINES........................................................................................................................ 2
# L’EMINES – School of Industrial Management........................................................................................ 3
## Pourquoi une Ecole dédiée au Management Industriel au Maroc ?................................................... 3
## Missions de l’Ecole .............................................................................................................................. 4
## Positionnement et Stratégie ............................................................................................................... 4
## Formation et Recherche...................................................................................................................... 6
## Partenariats et International ............................................................................................................... 7
## Organisation et Moyens ...................................................................................................................... 8
# LE CYCLE PREPARATOIRE INTEGRE.......................................................................................................... 9
## Le programme du CPI .......................................................................................................................... 9
## Les enseignants du CPI ...................................................................................................................... 10
## Les projets du CPI .............................................................................................................................. 10
# LE CYCLE INGENIEUR ............................................................................................................................. 12
## Le programme du CI .......................................................................................................................... 12
## Les enseignants du CI ........................................................................................................................ 13
## Les stages et la mobilité internationale ............................................................................................ 15
## Les projets du CI ................................................................................................................................ 16
# LA VIE ETUDIANTE ................................................................................................................................. 17
# SUIVI DES LAUREATS ET EMPLOI ........................................................................................................... 19
## Les statistiques d’emploi ................................................................................................................... 19
## Les employeurs.................................................................................................................................. 20
## Les start-up issues de l’EMINES......................................................................................................... 21
## Les formations complémentaires de nos diplômés .......................................................................... 21
## Les salaires des diplômés .................................................................................................................. 22

The image shows the EMINES building during its construction in 2013. It is a large, multi-story concrete structure with visible scaffolding. Construction equipment, including a crane and a concrete mixer truck, is present on the site under a cloudy sky.

**Bâtiment EMINES pendant sa construction en 2013, quelques mois avant son ouverture.**

1

EMINES – Informations Admis – Juin 2025

# LES ATOUTS DE L’EMINES

* Caractère unique de l’offre de formation de Managers Industriels au Maroc, et plus largement en Afrique (combinant les disciplines scientifiques, le monde du digital, de la robotique et des data sciences, le management, l’entrepreneuriat et le développement personnel).
* Adéquation des formations à la demande du monde du travail et aux évolutions de cette demande, avec une mention particulière sur les qualités d’adaptation des diplômés.
* Insertion professionnelle (principal critère de performance de l’Ecole) excellente au Maroc comme à l’étranger, avec des retours très positifs de l’ensemble des entreprises ou organismes qui recrutent les diplômés de l’Ecole.
* Formations aptes à faire émerger le « talent entrepreneurial » des étudiants avec 6 start-up actives qui vivent de leur travail et commencent à créer de l’emploi.
* Diplômés admis dans des formations complémentaires à l’étranger parmi les plus sélectives.
* Deux concours d’entrée très sélectifs et rigoureux, qui s’attachent à détecter le potentiel des candidats et ne comportent aucune barrière linguistique.
* Corps enseignant originaire des meilleures institutions d’enseignement supérieur internationales, et du monde de l’entreprise.
* Développement de « l’individu élève », géré comme un adulte responsable, placé au cœur du dispositif de formation, et acteur à part entière du développement de l’Ecole.
* Méthodes pédagogiques, et en particulier « Learning by Doing », très originales présentes dans toutes les disciplines, dès les classes préparatoires intégrées.
* Prise en charge des étudiants issus de milieux moins favorisés par un système de bourses sociales permettant une réelle mixité sociale à l’Ecole.
* Richesse de l’environnement UM6P sous toutes ses facettes, qui offre de nombreuses opportunités de développer son réseau, d’être confronté à d’autres profils, d’accéder aux enseignants des autres établissements, etc ...

The image shows a modern, rectangular building with a reddish-brown facade, featuring vertical window slits and a grassy area in front under a blue sky.

**Bâtiment EMINES aujourd’hui, après 12 années d’existence et 8 promotions diplômées.**

2

EMINES – Informations Admis – Juin 2025

# L’EMINES – School of Industrial Management

## Pourquoi une Ecole dédiée au Management Industriel au Maroc ?

Tout au long du XXème siècle, les établissements d’enseignement supérieur d’ingénierie nationaux et internationaux ont formé des diplômés plus ou moins spécialisés pour résoudre les questions essentiellement techniques posées au monde des entreprises. Leurs programmes de recherche suivaient cette direction, en consacrant l’essentiel de leurs efforts au développement de modèles scientifiques aptes à aider à la mise en place de ces solutions techniques.

En ce début de XXIème siècle, le besoin a très sensiblement évolué avec la mondialisation des marchés, avec l’évolution de plus en plus rapide à la fois des solutions techniques disponibles (en particulier digitales) et des systèmes organisationnels dans l’entreprise, et avec la démocratisation de l’accès à l’information et aux formations numériques. Le besoin d’ingénieurs (au sens de « cadres maîtrisant les techniques de leur spécialisation ») est désormais complété d’un besoin de « managers industriels » capables d’appréhender à la fois le caractère global des entreprises industrielles et les différentes composantes (économique, sociale, environnementale) de leur fonction. De même, les travaux de recherche ont dû, pour embrasser la globalité des questions posées, s’intéresser à de nouveaux sujets, profondément multidisciplinaires, et très proches des réalités d’application. L’émergence des projets industriels qui associent des pays du Sud (projet de pipe reliant le Maroc et le Nigéria par exemple) est en outre venu renforcer cette nécessaire prise en compte de la réalité, repoussant l’utilisation de « solutions catalogues » importées des pays du Nord et désormais inadaptées.

De plus, l’Afrique, dans sa multitude, doit répondre aux défis de la révolution numérique actuelle et de la transition énergétique qui transforment les chaînes de valeur au niveau mondial. Pour que ces évolutions majeures soient créatrices de valeur dans les industries traditionnelles telles que le secteur manufacturier, mais également dans d’autres secteurs essentiels au développement industriel tels que la logistique, l’agriculture, l’énergie, les communications, les services, la croissance verte et les villes intelligentes, le continent Africain doit disposer des compétences pour conduire ces changements. Pour cela, ce continent doit transformer ses modèles d’éducation et de recherche afin de former les talents qui contribueront à écrire cet avenir.

C’est dans ce contexte que l’EMINES - School of Industrial Management, première pierre de l’Université Mohammed VI Polytechnique, a été créée, avec pour mission de développer des programmes de formation et de recherche dans le domaine du management industriel, pour alimenter les entreprises existantes ou à créer, dans un esprit qui doit rester très proche de la pratique et du concret, et des réalités d’un environnement économique changeant et multiculturel.

L’EMINES a bénéficié pour cela de la proximité qu’elle a développé d’abord avec le groupe OCP puis avec le monde des entreprises marocaines, et plus largement des entreprises installées en Afrique. L’EMINES assoit ainsi ses programmes de formation et recherche sur un fort partenariat industriel, et offre à ses futurs diplômés des formations fondamentales scientifiques, techniques et socio-économiques solides, appuyées sur un fort développement de savoir-faire pratiques et de savoir-être entrepreneuriaux dans les différents domaines d’application du management industriel. Elle les prépare à devenir les futurs managers industriels du Maroc et du continent, créateurs de valeurs scientifiques, techniques, économiques et organisationnelles.

3

EMINES – Informations Admis – Juin 2025

# Missions de l’Ecole

Le développement de l’EMINES s’inscrit directement dans le projet de l’Université Mohammed VI Polytechnique, dont la vision peut se résumer comme suit :

* Devenir une Université de rang international, qui cherche à répondre aux enjeux du continent Africain que sont :
    - la gestion rationnelle des ressources,
    - l’industrialisation durable,
    - l’amélioration des politiques publiques,
    - le développement du capital humain,
* Qui donne la priorité à la recherche, l’innovation et l’entrepreneuriat pour la formation des futurs leaders socialement responsables de l’Afrique,
* Qui appuie son développement sur des partenariats académiques nationaux, et internationaux « en Afrique et pour l’Afrique »,
* Dans une structure à gestion privée, bénéficiant d’un Partenariat Public Privé, à but non lucratif et socialement juste.

Dans ce cadre, l’EMINES s’intéresse plus spécifiquement au thème « industrialisation durable », dans lequel elle a pour mission ou vocation première de **répondre aux enjeux de management de projets industriels d'entreprises (existantes ou à créer) dans l'environnement complexe de l’industrialisation durable de l’Afrique.**

Une mission ou vocation complémentaire, confiée à l’Ecole par l’Université, est de **préparer un corps enseignant en sciences de base** (mathématiques, physique et chimie, et sciences industrielles de l’ingénieur) pour les besoins propres de l’Université qui a fait le choix de former son personnel enseignants chercheurs, et plus largement pour les établissements d’enseignement d’excellence du pays et du continent.

> ***Pourquoi industrialiser le continent Africain ?***
>
> *L’Afrique produit seulement 1% de la valeur ajoutée manufacturière mondiale et donc importe massivement les produits manufacturés. Il y a là un champ de croissance énorme pour le continent, qui doit aller vers la transformation locale de ses matières premières (minérales ou agricoles).*
>
> *C’est en effet au niveau de cette transformation (c’est-à-dire de l’industrialisation) que se crée la valeur.*
>
> *A titre d’exemple, la Côte d’Ivoire et le Ghana, qui produisent à eux deux 60% du cacao mondial, ne reçoivent pour cela que 6% des recettes mondiales générées par le chocolat (estimées à 100 milliards de US $), car il n’y a pas d’industrie de transformation locale du cacao.*

## Positionnement et Stratégie

Pour accomplir ses missions, et respecter l’excellence internationale attendue par l’Université, l’Ecole est confrontée aux enjeux principaux (qui constituent aussi ses principaux indicateurs de performance) suivants :

4

EMINES – Informations Admis – Juin 2025

* montrer aux candidats que l’EMINES est une meilleure Ecole (à la fois en termes de contenus et en termes de débouchés et de salaires à la sortie) que la plupart de celles qu’ils vont trouver à l’étranger ;
* montrer aux employeurs, nationaux comme internationaux, que les produits de l’Ecole (ses diplômés et ses programmes de formation continue et de recherche) sont dotés des qualités qu’ils vont habituellement rechercher dans les pays du Nord ;
* permettre à ceux de ses étudiants qui ont une vocation entrepreneuriale de développer et lancer leur activité, dans des conditions de risque et de financement acceptables.

Son positionnement privilégie d’une part **l’excellence**, qui se traduit par la priorité donnée à la qualité de ses étudiants plutôt qu’à leur quantité et par des concours d’entrée très sélectifs tout en restant socialement justes, et d’autre part le développement de solutions d’enseignement et de recherche « **sur mesure** » adaptées aux réalités des entreprises du XXIème siècle, qui se traduit par une priorité donnée au terrain et à la pratique dans ses formations et ses recherches.

La stratégie de développement de l’Ecole peut alors être déclinée comme suit :

* Former, pour les entreprises du monde entier, des managers industriels généralistes, capables de penser « out of the box » et de créer de la valeur, et donc :
    - disposant d’un large socle de compétences disciplinaires et de soft skills renforcés,
    - « parlant couramment » informatique, robotique, data sciences,
    - familiarisés à la pratique et au concret du terrain industriel,
    - capables d’appréhender la complexité du monde (et en particulier du Sud) et des cultures d’entreprise, et la dimension internationale et multiculturelle des projets industriels,
    - préparés à apprendre à apprendre, afin d’être adaptés à l’évolution rapide des technologies et des organisations.
  A partir de tous les viviers de candidats possibles (i.e. sélectionnés par concours au niveau Bac pour le Cycle Préparatoire Intégré de l’Ecole, Bac +2 après CPGE pour le Cycle Ingénieur, Bac +5 après un diplôme d’Ingénieur pour le PhD et les Mastères Spécialisés, et tout au long de la vie pour les Formations Continues et les Executive Masters).

* Former un corps enseignant en sciences de base (mathématiques, physique et chimie, et sciences industrielles de l’ingénieur) combinant le niveau scientifique attendu des meilleurs agrégés et les qualités pédagogiques recherchées dans l’enseignement supérieur de rang international, à partir de candidats sélectionnés au niveau Bac +5 sur critères d’excellence (en particulier lors de leurs deux premières années de formation post-Bac).

* Accompagner le développement personnel des étudiants pour susciter et assister les vocations entrepreneuriales pendant la scolarité (undergraduate, graduate et formation professionnelle) dans un esprit de pré-incubation.

* Etudier les organisations industrielles et leurs processus de production (physiques, informationnels et/ou de prise de décision) dans une approche systémique de la supply chain, afin de créer des solutions de recherche innovantes adaptées à la réalité quotidienne des entreprises du Sud.

5

EMINES – Informations Admis – Juin 2025

# Formation et Recherche

L’EMINES anime les programmes de formation suivants :

*   Cycle Préparatoire Intégré en Management Industriel (depuis oct. 2013) - Autorisation n° 02/1528 du 03/06/2015 - Accréditations n° 02/1626 du 23/06/2015, n°04/2621 du 13/12/2018, et n° 2066/04 du 19/10/2023
*   Cycle Ingénieur en Management Industriel (depuis sept. 2014) - Autorisation n° 02/1528 du 03/06/2015 - Accréditation n° 02/1626 du 23/06/2015, n°04/2621 du 13/12/2018 et n° 2066/04 du 19/10/2023
*   Programme PhD Industriel (depuis nov. 2013)
*   Préparation Education Fellow (Agrégation) (depuis sept. 2019) – Options Mathématiques, Physique Chimie, Sciences Industrielles de l’Ingénieur
*   Formations Continues non diplômantes (depuis janv. 2018)
*   Executive Master en Supply Chain de l’Eau (depuis janv. 2020)
*   Executive Master en Posture et Outil du Manager Industriel (depuis mars 2023)

```mermaid
graph BT
    subgraph FORMATIONS_OFFERTES_PAR_L_EMINES [FORMATIONS OFFERTES PAR L'EMINES]
        CPI[Cycle Préparatoire Intégré]
        CI[Cycle Ingénieur]
        PhD[PhD & <br/> Prépa. <br/> Educ. <br/> Fellows]
        FC[FC non <br/> diplômante]
        FS[Formations <br/> Spéc.]
    end
    
    CPP[Classes <br/> Préparatoires <br/> Publiques]
    Bac[Baccalauréat]

    Bac --> CPI
    Bac --> CPP
    CPI --> CI
    CPP --> CI
    CI --> PhD
    CI --> FC
    CI --> FS
    Ext[ ] -- " " --> FS
    
    style Ext fill:none,stroke:none
    style FORMATIONS_OFFERTES_PAR_L_EMINES fill:#f9f9f9,stroke:#333,stroke-dasharray: 5 5
```

<table>
  <thead>
    <tr>
        <th>Effectifs Etudiants</th>
        <th>2013-2014</th>
        <th>2014-2015</th>
        <th>2015-2016</th>
        <th>2016-2017</th>
        <th>2017-2018</th>
        <th>2018-2019</th>
        <th>2019-2020</th>
        <th>2020-2021</th>
        <th>2021-2022</th>
        <th>2022-2023</th>
        <th>2023-2024</th>
        <th>2024-2025</th>
    </tr>
  </thead>
  <tbody>
    <tr>
        <td>Cycle préparatoire Intégré</td>
        <td>33</td>
        <td>62</td>
        <td>74</td>
        <td>59</td>
        <td>58</td>
        <td>75</td>
        <td>68</td>
        <td>67</td>
        <td>51</td>
        <td>63</td>
        <td>79</td>
        <td>72</td>
    </tr>
    <tr>
        <td>Cycle Ingénieur</td>
        <td>-</td>
        <td>13</td>
        <td>50</td>
        <td>97</td>
        <td>132</td>
        <td>140</td>
        <td>132</td>
        <td>174</td>
        <td>178</td>
        <td>188</td>
        <td>185</td>
        <td>204</td>
    </tr>
    <tr>
        <td>PhD (Doctorants) et Prépa Educ Fellow (Agrégation)</td>
        <td>2</td>
        <td>4</td>
        <td>6</td>
        <td>13</td>
        <td>22</td>
        <td>21</td>
        <td>37</td>
        <td>43</td>
        <td>36</td>
        <td>36</td>
        <td>27</td>
        <td>23</td>
    </tr>
    <tr>
        <td>Form. Executive diplômante</td>
        <td>-</td>
        <td>-</td>
        <td>6</td>
        <td>4</td>
        <td>9</td>
        <td>-</td>
        <td>7</td>
        <td>19</td>
        <td>12</td>
        <td>12</td>
        <td>30</td>
        <td>144</td>
    </tr>
    <tr>
        <td>TOTAL</td>
        <td>35</td>
        <td>79</td>
        <td>136</td>
        <td>173</td>
        <td>221</td>
        <td>236</td>
        <td>244</td>
        <td>303</td>
        <td>277</td>
        <td>299</td>
        <td>321</td>
        <td>443</td>
    </tr>
  </tbody>
</table>
**Historique de l’effectif étudiant de l’EMINES depuis sa création**

Les activités de recherche de l’Ecole sont structurées autour de :

*   la formation des étudiants en PhD (composée d’une année préparatoire de formation et d’initiation à la recherche, suivie par 3 années de doctorats dans le cadre du CEDoc de l’UM6P),
*   et de l’équipe de recherche en Management Industriel, qui s’appuie sur les Faculties recherche de l’EMINES et sur une dizaine de Pr. Affiliés recherche.

Les outils de recherche utilisés à l’Ecole sont principalement des outils d’optimisation, de simulation et de data sciences.

6

EMINES – Informations Admis – Juin 2025

## Partenariats et International

Le développement de l’Ecole s’appuie sur différents partenariats académiques internationaux :

* Pour la formation, l’Ecole bénéficie depuis sa création d’un partenariat privilégié avec l’Ecole des Mines de Paris (Mines Paris - PSL) avec lequel elle partage une option du cycle ingénieur (qui conduit une dizaine d’étudiants européens à passer quelques semaines chaque année avec les étudiants de l’Ecole), une Chaire d’enseignement et de recherche en Ressources Minérales pour la Transition Energétique, et un accès aux enseignants et aux supports pédagogiques. Elle s’appuie en outre sur une autre Chaire d’enseignement et de recherche en Data Sciences Industrielles passée avec l’Ecole Polytechnique pour l’animation d’une autre option du Cycle Ingénieur. L’Ecole utilise aussi le réseau international développé par l’Université, et en particulier aux Etats-Unis.

* Pour offrir à ses étudiants des mobilités de recherche à l’étranger (activité pédagogique obligatoire dans le Cycle Ingénieur), l’Ecole a développé une série de partenariats avec des Universités d’Amérique latine et d’Asie qui permettent d’envoyer chaque année l’ensemble des étudiants de 2<sup>ème</sup> année ingénieur en mobilité internationale pendant 3 à 4 mois. L’Ecole prend en charge directement les coûts liés de ces stages, ce qui est directement justifié par la stratégie de l’Ecole, qui veut proposer aux employeurs des diplômés ayant les mêmes compétences que celles de diplômés formés à l’étranger.

* Pour le recrutement de ses étudiants sub-sahariens, l’Ecole s’appuie sur un partenariat avec l’IPGEI à Nouakchott en Mauritanie, et sur le partenariat de l’Université avec l’INP-HB à Yamoussoukro en Côte d’Ivoire.

* Pour ses activités de recherche, l’Ecole s’appuie sur ses partenariats en France avec le réseau universitaire constitué par ses Pr. Affiliés recherche (Paris Dauphine, Paris II, Université d’Auvergne, Université de Nantes, Mines Paris – PSL, et Ecole Polytechnique en particulier), pour accompagner la formation doctorale et post-doctorale.

* L’Ecole utilise enfin pleinement son réseau de relations entreprises pour enrichir ses formations, avec des intervenants du groupe OCP, de SONASID, des projets co-animés avec RATP Dev, des modules co-construits avec Jesa, etc …

Une carte du monde illustre l'étendue mondiale des partenariats de l'UM6P, avec de nombreux logos d'institutions partenaires répartis sur tous les continents : Amérique du Nord, Amérique du Sud, Europe, Afrique, Asie et Océanie.

**Les principaux établissements partenaires de l’UM6P**

7

EMINES – Informations Admis – Juin 2025

## Organisation et Moyens

L’EMINES a été créée en 2013 en tant qu’établissement relevant de l’Université Mohammed VI Polytechnique (UM6P) et a bénéficié de l’autorisation n° 404/13 du 28/11/2014. Elle est installée à Ben Guerir, dans la province de Rehamna, au siège de l’UM6P.

L’Ecole est structurée en unités académiques et en services fonctionnels. Elle appuie en outre son fonctionnement sur les organes internes suivants :

*   Comité Pédagogique, en charge de la validation et du suivi des programmes de formation, de l’évaluation des enseignements, et de la validation des recrutements des enseignants ;
*   Comité de la Recherche, en charge des questions relatives à la formation et au suivi des étudiants en PhD (doctorants) et aux programmes de recherche ;
*   Comité des Etudes, en charge de l’admission, du suivi et de la sanction des Etudes ;
*   Jurys de concours pour chaque programme, placés auprès du Comités des Etudes ;
*   Commission des Bourses (des bourses sociales et bourses d’Excellence) ;
*   Conseil d’Etablissement, en charge de la validation des orientations stratégiques de l’Ecole.

Les étudiants y sont représentés à la fois dans le Comité Pédagogique, dans le Comité des Etudes tant que de besoin, et dans le Conseil d’Etablissement.

Le personnel en charge de la formation, de la recherche, et plus largement du fonctionnement de l’établissement est composé d’un corps académique réunissant 58 enseignants responsables + environ 50 intervenants ponctuels, et 24 personnels techniques et administratifs.

Le bâtiment occupé par l’EMINES comprend 4 amphithéâtres, 40 salles de cours, 10 salles informatiques, 3 laboratoires d’enseignement, et 50 bureaux. L’Ecole utilise de plus les autres infrastructures de l’Université, et en particulier les résidences étudiantes, les unités de restauration, la bibliothèque, les espaces de détente étudiants et les installations sportives.

L’Ecole s’appuie sur différents outils numériques et de communication interne qui participent à la mesure de ses performances et au soutien de son développement :

*   un système de gestion pédagogique de scolarité (système OASIS) qui regroupe toutes les données sur les étudiants, leur parcours, leurs résultats, les enseignants, le descriptif de chaque enseignement, etc ...,
*   une plateforme « e-Learning » qui offre aux enseignants et aux étudiants un support de communication et d’échange de cours, devoirs, etc ....

Le budget de fonctionnement de l’établissement provient en moyenne de :

*   10% de frais de scolarité de la formation initiale pris en charge par les étudiants ;
*   40% de frais de scolarité de la formation initiale pris en charge par des bourses sociales et d’excellence de la Fondation Ibn Rochd ;
*   10% de frais de formation de la préparation Education Fellow (agrégation) ;
*   40% de Chaires et de contrats de recherche et de formation continue passés directement auprès des entreprises partenaires.

A ce budget, s’ajoute des dépenses d’investissement, principalement dédiées au matériel informatique et à la réalisation de projets entrepreneuriaux élèves.

8

EMINES – Informations Admis – Juin 2025

# LE CYCLE PREPARATOIRE INTEGRE
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

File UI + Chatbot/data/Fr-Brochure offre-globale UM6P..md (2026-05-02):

UM6P
University Mohammed VI Polytechnic
Année Académique 2025 - 2026

Three students, two men and one woman, are sitting on a bench and talking. In the background, there is a large, golden, geometric wireframe sculpture.

# Transforming potential into impact
## Offre Globale de Formations

Empowering Minds.
1

# À propos de l’UM6P

## BIENVENUE DANS L’UNIVERS UM6P : UN MODÈLE D’EXCELLENCE EN PLEINE EXPANSION

Université jeune et ambitieuse située au Maroc et profondément ancrée dans des valeurs nobles telles que l’éthique, l’inclusion, la durabilité et l’engagement communautaire, nous proposons à nos étudiant-es un large éventail de programmes de haut niveau (cycles ingénieurs, licences, masters, doctorats, …) dans des domaines aussi variés que les sciences et technologies, l’ingénierie, la santé, le business et le management, l’économie, et les sciences sociales.

En pleine expansion, notre institution aspire à figurer parmi les plus grandes références internationales à court terme, grâce à notre recherche et notre enseignement de classe mondiale.
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

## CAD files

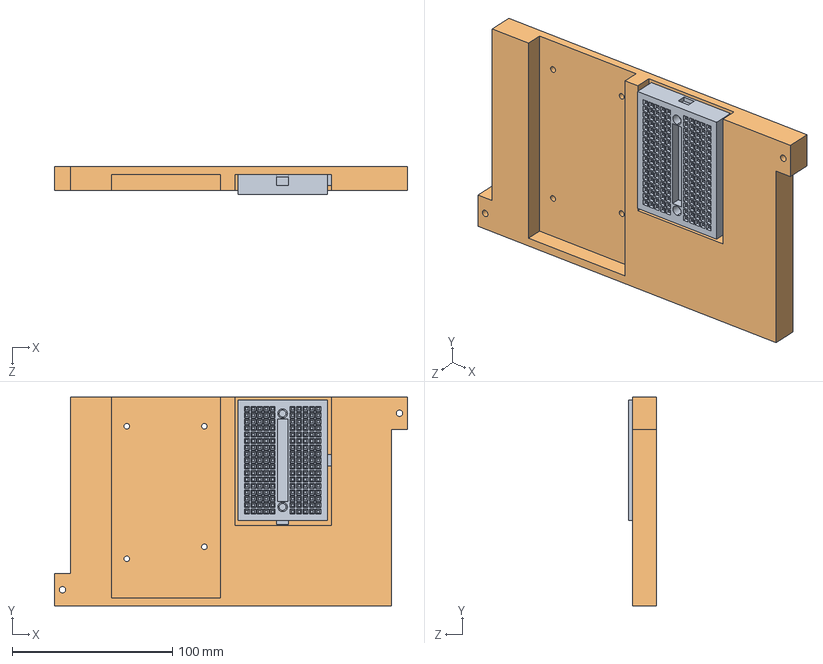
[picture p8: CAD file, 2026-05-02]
SolidWorks CAD/assem_arduino_plaque.SLDASM
220.0 x 130.0 x 17.5 mm
piece support arduino et plaque d'essai
BreadBord.step

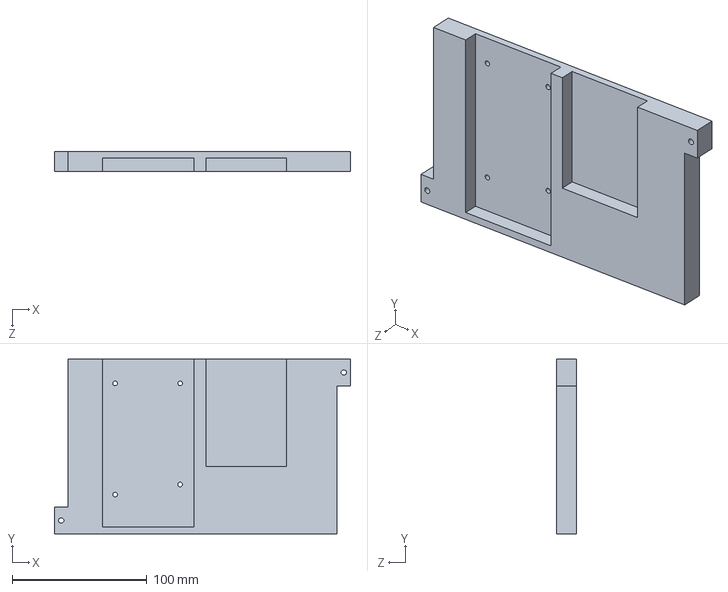
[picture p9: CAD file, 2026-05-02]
SolidWorks CAD/Assem support arduino.SLDASM
220.0 x 130.0 x 15.0 mm

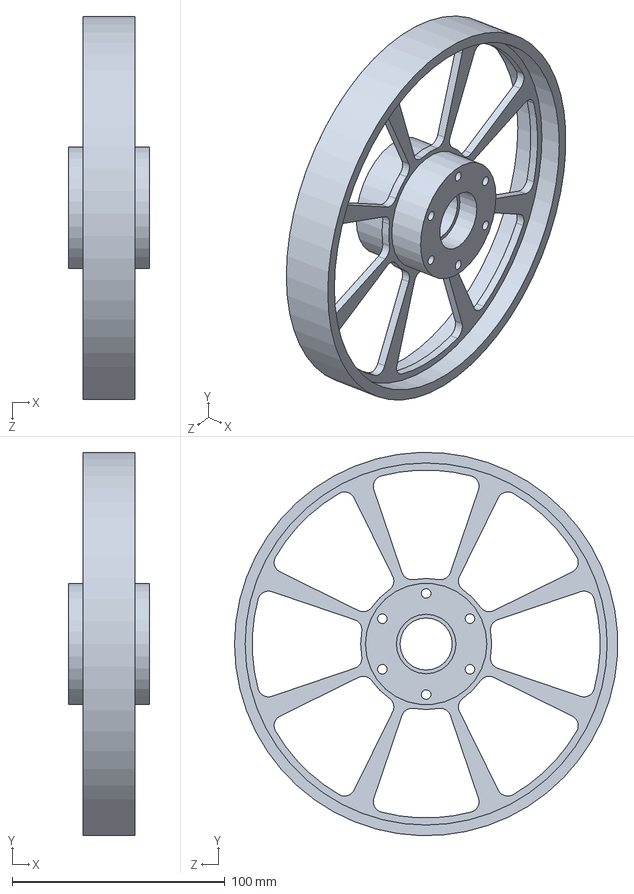
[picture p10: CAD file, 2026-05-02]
SolidWorks CAD/assem_roue.SLDASM
38.0 x 179.9 x 179.8 mm

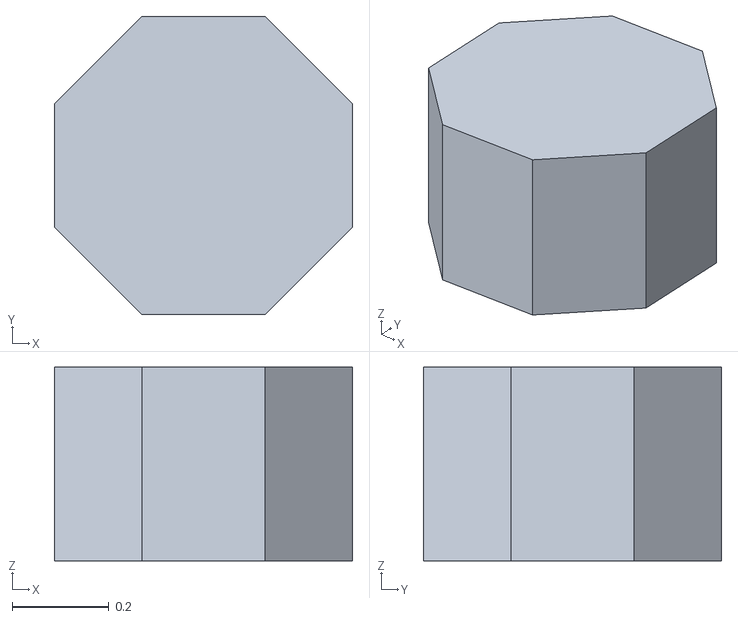
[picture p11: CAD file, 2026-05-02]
Navigation (NAV2)/slam/test/src/robot_description/meshes/octagon_base.stl
0.616 x 0.616 x 0.4

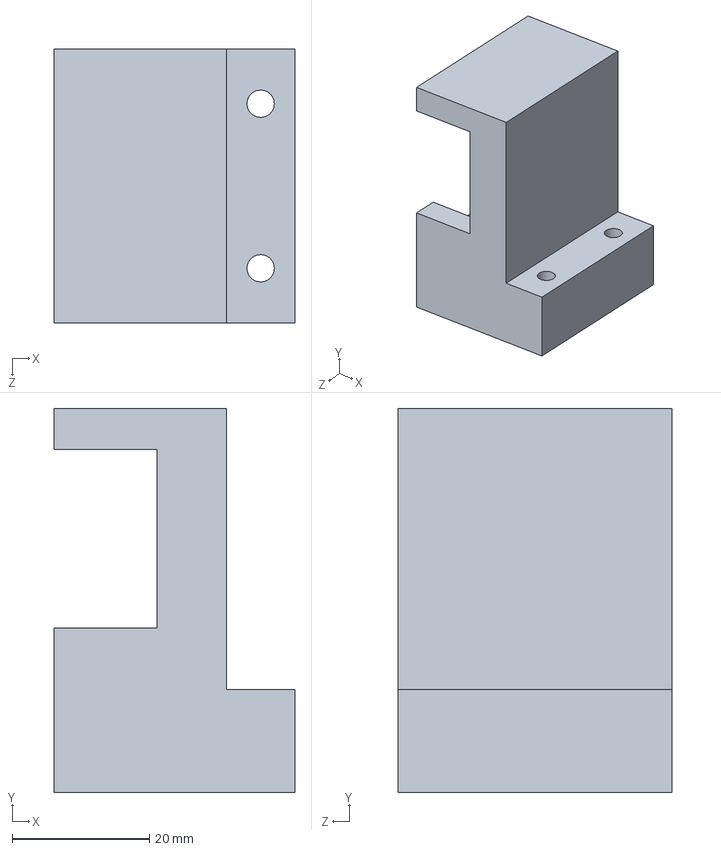
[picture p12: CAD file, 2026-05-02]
SolidWorks CAD/supp_minipc.SLDPRT
35.1 x 56.0 x 40.0 mm

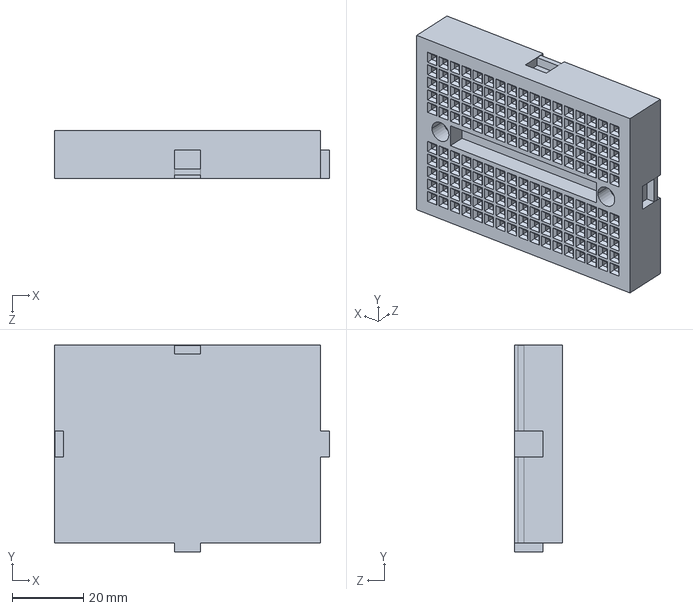
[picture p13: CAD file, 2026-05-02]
SolidWorks CAD/BreadBord.step.SLDPRT
77.4 x 58.2 x 13.6 mm

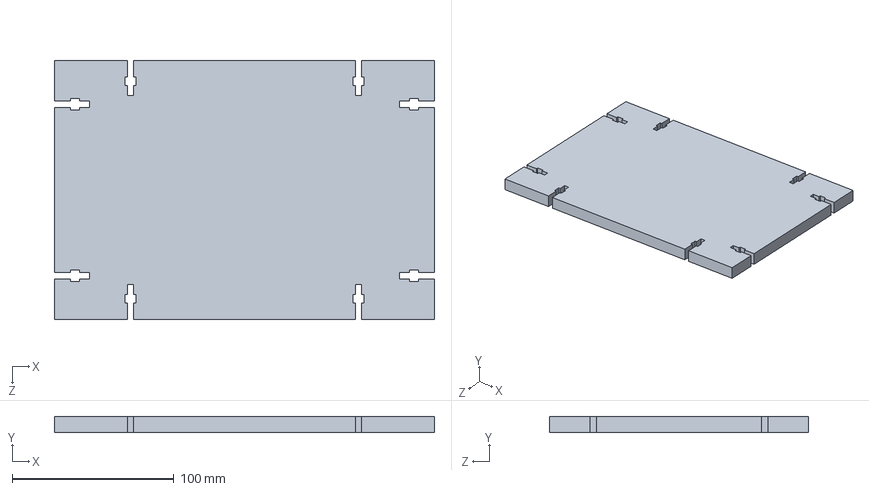
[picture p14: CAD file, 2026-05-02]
SolidWorks CAD/mur deririere.SLDPRT
235.0 x 10.0 x 160.0 mm

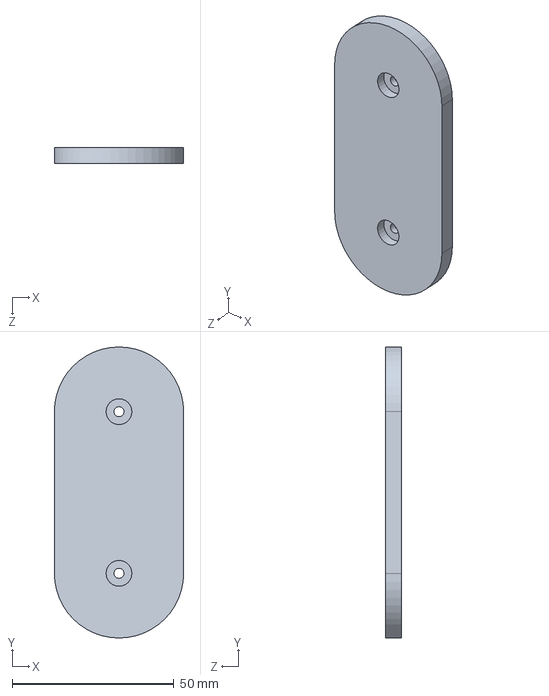
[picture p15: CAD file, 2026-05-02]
SolidWorks CAD/plaque_conductrice_plaque_new.SLDPRT
40.0 x 90.0 x 5.00 mm

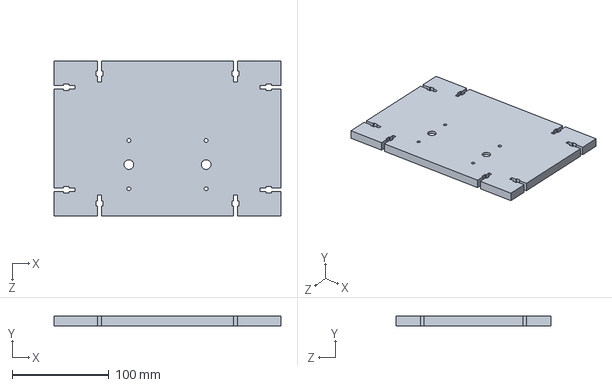
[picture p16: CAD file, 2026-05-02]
SolidWorks CAD/mur face.SLDPRT
235.0 x 10.0 x 160.0 mm

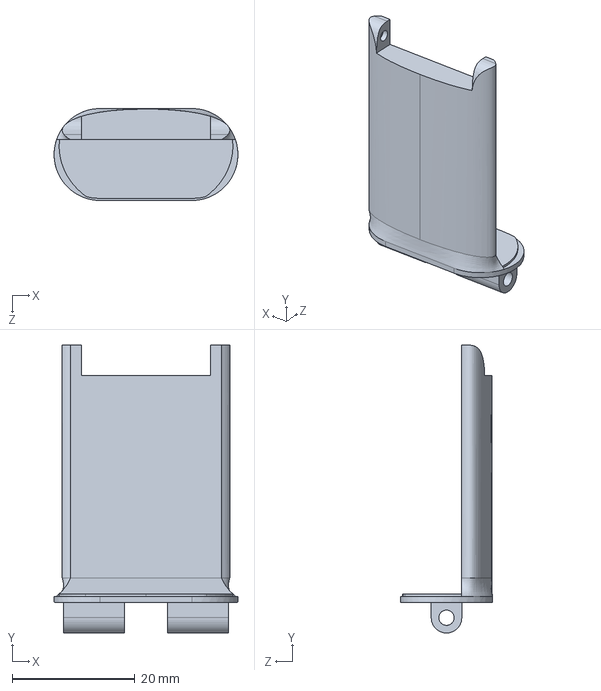
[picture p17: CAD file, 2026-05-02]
SolidWorks CAD/mount.SLDPRT
30.0 x 47.0 x 15.0 mm

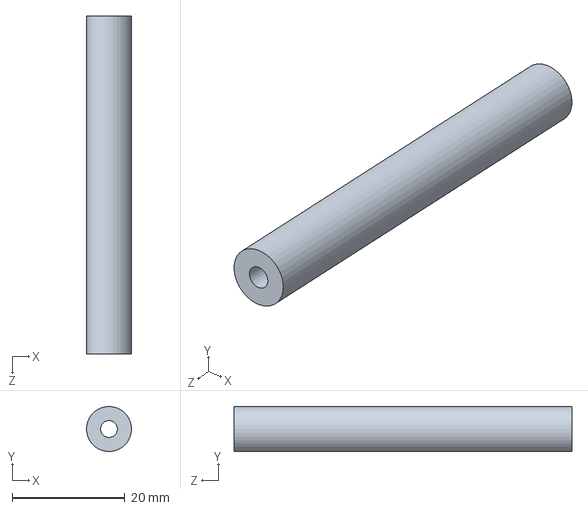
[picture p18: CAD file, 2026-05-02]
SolidWorks CAD/guide_ressort.SLDPRT
8.00 x 8.00 x 60.0 mm

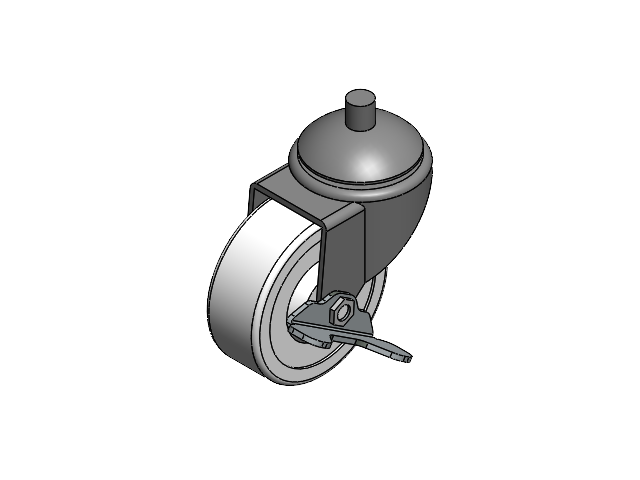
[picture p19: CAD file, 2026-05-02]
SolidWorks CAD/CASTER WHEEL (2.5inch) ASSY.SLDPRT.SLDASM
CASTER WHEEL BASE
RUBBER WHEEL (2.5inch)
CASTER WHEEL BASE LOCK

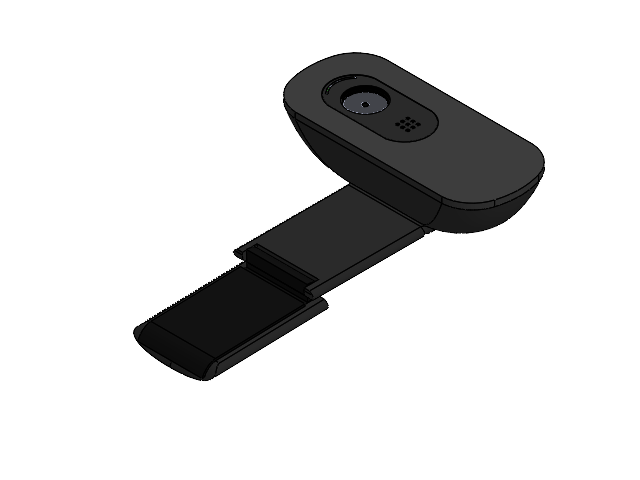
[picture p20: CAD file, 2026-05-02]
SolidWorks CAD/logitech_webcam_c270.SLDASM
logitech_webcam_c270
mount
mount_bottom

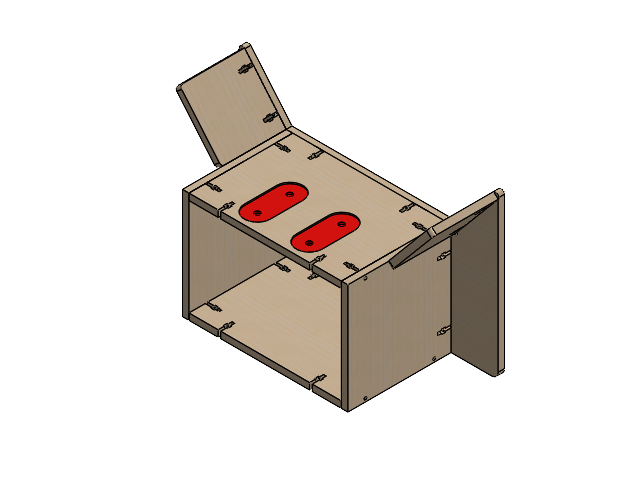
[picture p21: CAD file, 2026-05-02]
SolidWorks CAD/Assem1station.SLDASM
support charge
paroi direction 1 x 2
mur 1 x 2
mur deririere
mur face
plaque_conductrice_plaque_new x 2

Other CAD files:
SolidWorks CAD/LCD 7 inch.SLDASM
SolidWorks CAD/assem_moteur_roue.SLDASM
SolidWorks CAD/piece support arduino et plaque d'essai.SLDPRT
SolidWorks CAD/Part1.SLDPRT
SolidWorks CAD/Arduino Mega 2560.SLDPRT
SolidWorks CAD/Arduino Mega 2560.step
SolidWorks CAD/CASTER WHEEL BASE LOCK.SLDPRT
SolidWorks CAD/CASTER WHEEL BASE.SLDPRT
SolidWorks CAD/Part2.SLDPRT
SolidWorks CAD/Port_male.SLDPRT
SolidWorks CAD/RUBBER WHEEL (2.5inch).SLDPRT
SolidWorks CAD/SD161.SLDPRT
SolidWorks CAD/Stepper Motor Flexible Coupling 6,35 x 8 mm.SLDPRT
SolidWorks CAD/Vis_guide.SLDPRT
SolidWorks CAD/accouplement.SLDPRT
SolidWorks CAD/arbre.SLDPRT
SolidWorks CAD/back.SLDPRT
SolidWorks CAD/base.SLDPRT
SolidWorks CAD/batterie_Turnigy.SLDPRT
SolidWorks CAD/chassis_v2.SLDPRT
SolidWorks CAD/fourche en T.SLDPRT
SolidWorks CAD/front.SLDPRT
SolidWorks CAD/habillage_piece.SLDPRT
SolidWorks CAD/habillage_port_piece.SLDPRT
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

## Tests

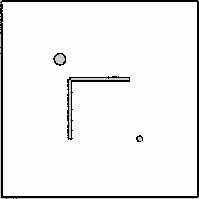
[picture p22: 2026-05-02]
Navigation (NAV2)/slam/test/maps/test_world_map.png

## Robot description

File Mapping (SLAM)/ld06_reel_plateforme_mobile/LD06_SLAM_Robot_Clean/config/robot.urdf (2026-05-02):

<?xml version="1.0"?>
<!--
  Robot URDF Description
  ======================
  Octagonal base robot with LD06 LiDAR
  
  Dimensions:
    - Height:               520mm (0.52m)
    - Octagonal base:       255mm per side, 615.62mm flat-to-flat
    - Wheel track (between wheels): 488mm (0.488m)
    - LiDAR height:         mounted on top (z = 0.52m from ground)
    - Wheel diameter:       65mm (0.065m), width ~26mm
-->
<robot name="slam_robot">

  <!-- ============================================================ -->
  <!--  BASE FOOTPRINT (ground projection)                          -->
  <!-- ============================================================ -->
  <link name="base_footprint"/>

  <joint name="base_footprint_to_base_link" type="fixed">
    <parent link="base_footprint"/>
    <child link="base_link"/>
    <!-- base_link is at wheel axle height = wheel_radius = 0.0325m -->
    <origin xyz="0 0 0.0325" rpy="0 0 0"/>
  </joint>

  <!-- ============================================================ -->
  <!--  BASE LINK (octagonal body)                                  -->
  <!-- ============================================================ -->
  <link name="base_link">
    <visual>
      <origin xyz="0 0 0.2275" rpy="0 0 0"/>
      <!-- Approximate octagon as a cylinder with circumradius ~0.308m -->
      <geometry>
        <cylinder radius="0.30781" length="0.455"/>
      </geometry>
      <material name="chassis_grey">
        <color rgba="0.4 0.4 0.4 1.0"/>
      </material>
    </visual>
    <collision>
      <origin xyz="0 0 0.2275" rpy="0 0 0"/>
      <geometry>
        <cylinder radius="0.30781" length="0.455"/>
      </geometry>
    </collision>
    <inertial>
      <origin xyz="0 0 0.2275" rpy="0 0 0"/>
      <mass value="5.0"/>
      <inertia ixx="0.1" ixy="0" ixz="0" iyy="0.1" iyz="0" izz="0.1"/>
    </inertial>
  </link>

  <!-- ============================================================ -->
  <!--  LEFT WHEEL                                                  -->
  <!-- ============================================================ -->
  <link name="left_wheel">
    <visual>
      <origin xyz="0 0 0" rpy="1.5708 0 0"/>
      <geometry>
        <cylinder radius="0.0325" length="0.026"/>
      </geometry>
      <material name="wheel_black">
        <color rgba="0.1 0.1 0.1 1.0"/>
      </material>
    </visual>
    <collision>
      <origin xyz="0 0 0" rpy="1.5708 0 0"/>
      <geometry>
        <cylinder radius="0.0325" length="0.026"/>
      </geometry>
    </collision>
    <inertial>
      <mass value="0.2"/>
      <inertia ixx="0.0001" ixy="0" ixz="0" iyy="0.0001" iyz="0" izz="0.0001"/>
    </inertial>
  </link>

  <joint name="left_wheel_joint" type="continuous">
    <parent link="base_link"/>
    <child link="left_wheel"/>
    <!-- Wheel at axle height (base_link origin), offset left by half track width -->
    <origin xyz="0 0.244 0" rpy="0 0 0"/>
    <axis xyz="0 1 0"/>
  </joint>

  <!-- ============================================================ -->
  <!--  RIGHT WHEEL                                                 -->
  <!-- ============================================================ -->
  <link name="right_wheel">
    <visual>
      <origin xyz="0 0 0" rpy="1.5708 0 0"/>
      <geometry>
        <cylinder radius="0.0325" length="0.026"/>
      </geometry>
      <material name="wheel_black">
        <color rgba="0.1 0.1 0.1 1.0"/>
      </material>
    </visual>
    <collision>
      <origin xyz="0 0 0" rpy="1.5708 0 0"/>
      <geometry>
        <cylinder radius="0.0325" length="0.026"/>
      </geometry>
    </collision>
    <inertial>
      <mass value="0.2"/>
      <inertia ixx="0.0001" ixy="0" ixz="0" iyy="0.0001" iyz="0" izz="0.0001"/>
    </inertial>
  </link>

  <joint name="right_wheel_joint" type="continuous">
    <parent link="base_link"/>
    <child link="right_wheel"/>
    <!-- Wheel at axle height (base_link origin), offset right by half track width -->
    <origin xyz="0 -0.244 0" rpy="0 0 0"/>
    <axis xyz="0 1 0"/>
  </joint>

  <!-- ============================================================ -->
  <!--  FRONT CASTER (for stability, simplified)                    -->
  <!-- ============================================================ -->
  <link name="front_caster">
    <visual>
      <origin xyz="0 0 0" rpy="0 0 0"/>
      <geometry>
        <sphere radius="0.0325"/>
      </geometry>
      <material name="caster_grey">
        <color rgba="0.3 0.3 0.3 1.0"/>
      </material>
    </visual>
    <collision>
      <origin xyz="0 0 0" rpy="0 0 0"/>
      <geometry>
        <sphere radius="0.0325"/>
      </geometry>
    </collision>
    <inertial>
      <mass value="0.1"/>
      <inertia ixx="0.00001" ixy="0" ixz="0" iyy="0.00001" iyz="0" izz="0.00001"/>
    </inertial>
  </link>

  <joint name="front_caster_joint" type="fixed">
    <parent link="base_link"/>
    <child link="front_caster"/>
    <!-- Caster at front of robot, at ground contact level (same as wheels) -->
    <origin xyz="0.20 0 0" rpy="0 0 0"/>
  </joint>

  <!-- ============================================================ -->
  <!--  LD06 LiDAR                                                  -->
  <!-- ============================================================ -->
  <link name="base_laser">
    <visual>
      <origin xyz="0 0 0" rpy="0 0 0"/>
      <geometry>
        <cylinder radius="0.035" length="0.04"/>
      </geometry>
      <material name="lidar_blue">
        <color rgba="0.0 0.3 0.8 1.0"/>
      </material>
    </visual>
    <collision>
      <origin xyz="0 0 0" rpy="0 0 0"/>
      <geometry>
        <cylinder radius="0.035" length="0.04"/>
      </geometry>
    </collision>
    <inertial>
      <mass value="0.1"/>
      <inertia ixx="0.00001" ixy="0" ixz="0" iyy="0.00001" iyz="0" izz="0.00001"/>
    </inertial>
  </link>

  <joint name="base_link_to_base_laser" type="fixed">
    <parent link="base_link"/>
    <child link="base_laser"/>
    <!-- LiDAR on top of the robot: height 520mm - 32.5mm(wheel axle) = 487.5mm above base_link -->
    <!-- Rotated -90° yaw to align LiDAR forward with robot forward -->
    <origin xyz="0 0 0.4875" rpy="0 0 -1.5708"/>
  </joint>

</robot>

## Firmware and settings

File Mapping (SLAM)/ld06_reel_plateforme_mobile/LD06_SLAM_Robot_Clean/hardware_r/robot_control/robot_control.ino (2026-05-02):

#include <Servo.h>


// === Enhanced Robot Control with Servo Steering ===
// Motor control + Encoder reading + Servo steering + ROS2 command interface

// --- Pin Definitions ---
const int ENCA = 2;           // Encoder channel A (interrupt)
const int ENCB = 3;           // Encoder channel B
const int MOTOR_PWM = 6;      // PWM pin for motor speed
const int MOTOR_DIR = 7;      // Motor direction pin
const int SERVO_PIN = 8;      // Servo motor pin

// --- Robot Parameters ---
const int pulsesPerRevolution = 360;  // Encoder ticks per revolution
const float wheelDiameter = 0.065;    // Wheel diameter [m]
const float wheelBase = 0.15;         // Distance between wheels [m]

// --- Servo Parameters ---
const int SERVO_CENTER = 90;          // Center position (straight)
const int SERVO_MAX_LEFT = 135;       // Maximum left turn (was 45, swapped because servo mounted backwards)
const int SERVO_MAX_RIGHT = 45;       // Maximum right turn (was 135, swapped because servo mounted backwards)

// --- Variables ---
volatile long encoderCount = 0;
unsigned long lastTime = 0;
float rpm = 0.0;
float linearSpeed = 0.0;
float steeringAngle = 0.0;            // Current steering angle in degrees

// Target commands (from serial/ROS)
float targetSpeed = 0.0;              // Target linear speed [m/s]
float targetSteering = 0.0;           // Target steering angle [-1.0 to 1.0]

Servo steeringServo;

void setup() {
  Serial.begin(115200);
  
  // Motor pins
  pinMode(ENCA, INPUT_PULLUP);
  pinMode(ENCB, INPUT_PULLUP);
  pinMode(MOTOR_PWM, OUTPUT);
  pinMode(MOTOR_DIR, OUTPUT);
  
  // Servo setup
  steeringServo.attach(SERVO_PIN);
  steeringServo.write(SERVO_CENTER);
  
  // Encoder interrupt
  attachInterrupt(digitalPinToInterrupt(ENCA), encoderISR, RISING);
  
  // Stop motor initially
  analogWrite(MOTOR_PWM, 0);
  
  Serial.println("Robot control ready!");
  Serial.println("Commands: S<speed> T<steering>");
  Serial.println("Example: S0.2 (0.2 m/s), T0.5 (half right turn)");
}

void loop() {
  // Read serial commands
  readSerialCommands();
  
  // Update motor control
  updateMotorControl();
  
  // Update servo steering
  updateSteering();
  
  // Calculate and publish odometry (10Hz)
  unsigned long now = millis();
  if (now - lastTime >= 100) {
    calculateOdometry();
    publishOdometry();
    lastTime = now;
  }
}

void readSerialCommands() {
  // Read up to 3 commands per loop to avoid blocking
  int commandsRead = 0;
  while (Serial.available() > 0 && commandsRead < 3) {
    String cmd = Serial.readStringUntil('\n');
    cmd.trim();
    
    if (cmd.length() == 0) continue;  // Skip empty commands
    
    commandsRead++;
    
    // Parse speed command: S<value>
    if (cmd.startsWith("S")) {
      targetSpeed = cmd.substring(1).toFloat();
      targetSpeed = constrain(targetSpeed, -0.5, 0.5); // Limit to ±0.5 m/s
    }
    // Parse steering command: T<value> (-1.0 to 1.0)
    else if (cmd.startsWith("T")) {
      String valueStr = cmd.substring(1);
      targetSteering = valueStr.toFloat();
      targetSteering = constrain(targetSteering, -1.0, 1.0);
      // Debug output
      Serial.print("DEBUG: Received T command, value=");
      Serial.print(valueStr);
      Serial.print(", parsed=");
      Serial.println(targetSteering);
    }
    // Stop command
    else if (cmd == "STOP") {
      targetSpeed = 0.0;
      targetSteering = 0.0;
    }
  }
}

void updateMotorControl() {
  // If steering but not moving, use minimum speed for steering
  float effectiveSpeed = targetSpeed;
  if (abs(targetSpeed) < 0.01 && abs(targetSteering) > 0.1) {
    // Turn in place with slow forward motion
    effectiveSpeed = 0.05;  // Minimum speed for steering
  }
  
  if (abs(effectiveSpeed) < 0.01) {
    // Stop motor
    analogWrite(MOTOR_PWM, 0);
    return;
  }
  
  // Set direction
  if (effectiveSpeed > 0) {
    digitalWrite(MOTOR_DIR, HIGH);  // Forward
  } else {
    digitalWrite(MOTOR_DIR, LOW);   // Backward
  }
  
  // Simple speed control (map 0-0.5 m/s to PWM 0-255)
  int pwm = (int)(abs(effectiveSpeed) / 0.5 * 255);
  pwm = constrain(pwm, 0, 255);
  analogWrite(MOTOR_PWM, pwm);
}

void updateSteering() {
  // Map steering command (-1.0 to 1.0) to servo angle
  // -1.0 = full left, 0.0 = center, 1.0 = full right
  int servoAngle;
  if (targetSteering < 0) {
    // Left turn
    servoAngle = map(targetSteering * 1000, -1000, 0, SERVO_MAX_LEFT, SERVO_CENTER);
  } else {
    // Right turn
    servoAngle = map(targetSteering * 1000, 0, 1000, SERVO_CENTER, SERVO_MAX_RIGHT);
  }
  
  steeringServo.write(servoAngle);
  steeringAngle = targetSteering * 45.0; // Convert to degrees for display
}

void calculateOdometry() {
  noInterrupts();
  long count = encoderCount;
  encoderCount = 0;
  interrupts();
  
  // Calculate RPM
  float revs = (float)count / pulsesPerRevolution;
  rpm = revs * 600.0; // 600 = (60 seconds / 0.1 second interval)
  
  // Calculate linear speed
  linearSpeed = (rpm * 3.1416 * wheelDiameter) / 60.0;
}

void publishOdometry() {
  // Send data in same format as before for compatibility with Arduino bridge
  Serial.print("RPM:");
  Serial.print(rpm, 2);
  Serial.print(",Speed:");
  Serial.print(linearSpeed, 4);
  Serial.print(",Steering:");
  Serial.println(steeringAngle, 2);
}

void encoderISR() {
  int b = digitalRead(ENCB);
  if (b > 0) {
    encoderCount++;
  } else {
    encoderCount--;
  }
}

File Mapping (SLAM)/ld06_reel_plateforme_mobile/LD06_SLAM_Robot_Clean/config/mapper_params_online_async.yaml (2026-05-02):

# SLAM Toolbox Configuration for LD06 LiDAR
# Online Async Mode - Real-time mapping while moving

slam_toolbox:
  ros__parameters:
    
    # Plugin Configuration
    odom_frame: odom
    map_frame: map
    base_frame: base_link
    scan_topic: /scan
    
    # ROS Parameters
    use_sim_time: false
    mode: mapping  # localization or mapping
    
    # Map Management
    # map_file_name: /tmp/slam_map  # Only set when loading a previous map
    map_start_pose: [0.0, 0.0, 0.0]
    map_start_at_dock: false
    
    # Solver Parameters
    solver_plugin: solver_plugins::CeresSolver
    ceres_linear_solver: SPARSE_NORMAL_CHOLESKY
    ceres_preconditioner: SCHUR_JACOBI
    ceres_trust_strategy: LEVENBERG_MARQUARDT
    ceres_dogleg_type: TRADITIONAL_DOGLEG
    ceres_loss_function: None
    
    # SLAM Parameters
    debug_logging: false
    throttle_scans: 1
    transform_publish_period: 0.02  # 50 Hz for smooth TF
    map_update_interval: 5.0
    resolution: 0.05  # 5cm resolution
    max_laser_range: 20.0  # Increased to handle long corridors
    minimum_time_interval: 0.5
    transform_timeout: 0.5
    tf_buffer_duration: 30.0
    stack_size_to_use: 40000000
    enable_interactive_mode: true
    
    # General Parameters
    use_scan_matching: true
    use_scan_barycenter: true
    minimum_travel_distance: 0.05  # 5cm - more frequent updates for better tracking
    minimum_travel_heading: 0.05   # ~3 degrees - more sensitive to rotation
    scan_buffer_size: 10
    scan_buffer_maximum_scan_distance: 10.0
    link_match_minimum_response_fine: 0.2  # Higher threshold = trust scan matching more
    link_scan_maximum_distance: 2.0  # Increased search radius for scan matching
    loop_search_maximum_distance: 4.0  # Larger loop closure search
    do_loop_closing: true
    loop_match_minimum_chain_size: 5  # Less strict for loop closure
    loop_match_maximum_variance_coarse: 5.0  # More tolerant to odometry drift
    loop_match_minimum_response_coarse: 0.25  # Lower threshold
    loop_match_minimum_response_fine: 0.35  # Lower threshold
    
    # Correlation Parameters
    correlation_search_space_dimension: 0.5
    correlation_search_space_resolution: 0.01
    correlation_search_space_smear_deviation: 0.1
    
    # Loop Closure Parameters
    loop_search_space_dimension: 8.0
    loop_search_space_resolution: 0.05
    loop_search_space_smear_deviation: 0.03
    
    # Scan Matcher Parameters
    distance_variance_penalty: 0.3  # Lower = trust odometry less
    angle_variance_penalty: 0.5  # Lower = trust odometry rotation less
    fine_search_angle_offset: 0.0174  # 1 degree - wider search
    coarse_search_angle_offset: 0.524  # 30 degrees - much wider for bad odometry
    coarse_angle_resolution: 0.0524    # 3 degrees - finer resolution
    minimum_angle_penalty: 0.7  # Lower = more tolerant
    minimum_distance_penalty: 0.3  # Lower = more tolerant
    use_response_expansion: true

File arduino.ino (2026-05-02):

#include <SimpleTimer.h>
#include <Wire.h>
SimpleTimer timer;

// --- MPU-6050 ---
const uint8_t MPU_ADDR = 0x68;
double gyro_bias_x = 0, gyro_bias_y = 0, gyro_bias_z = 0;
double w_gyro_filtered = 0;
double w_gyro_x_filtered = 0, w_gyro_y_filtered = 0;
const double alpha_gyro = 0.25;
bool mpu_ok = false;

// --- DETECTION ANOMALIES ---
double accel_z_baseline = 1.0;
double accel_z_filtered = 1.0;
const double ACCEL_Z_THRESHOLD = 0.08;  // catches 1-2° tilts from floor bumps (was 0.3)
const double DIVERGENCE_THRESHOLD = 0.3;
const int ANOMALY_HOLD_CYCLES = 25;  // ~200ms à 128Hz
int anomaly_counter = 0;
bool anomaly_active = false;

// --- MOTEURS ---
const int M1_DIR = 7; const int M1_PWM = 6;
const int M2_DIR = 4; const int M2_PWM = 5;

// --- ENCODEURS ---
#define ENC1_A 2 
#define ENC1_B 3
#define ENC2_A 18
#define ENC2_B 19

// --- BATTERIE GRAPHENE 3S ---
const int PIN_BATTERIE = A15;
const int PIN_RELAY = 10;
const float VOLT_MAX = 12.6;
const float VOLT_MIN = 10.2;
const float VOLT_STOP = 10;
const float RATIO_CAPTEUR = 4.841;
bool batterie_critique = false;
bool relay_active = false;

// --- GEOMETRIE ROBOT ---
const double RAYON_ROUE = 0.10; 
const double ENTRAXE = 0.488;    

// --- PARAMETRES PHYSIQUES ---
const int rapport_reducteur = 131;
const int resolution = 64;
const int fe = 128; 
const double dt = 1.0 / fe; 

// --- PID + FEEDFORWARD ---
double Kp = 4.0; double Ki = 20.0; double Kd = 0.02; double Kf = 2.0;  

// --- BOUCLE W EXTERNE ---
double Kp_w = 0.8;
double Ki_w = 1.5;
double w_err_sum = 0;

// --- DEADBAND / KICK-START ---
const int PWM_DEADBAND = 20;
const int PWM_KICK     = 45;
const double SLIP_THRESHOLD = 30.0;
const double TILT_RATE_THRESHOLD = 0.15;  // rad/s — catches floor bump tilting via gyro X/Y

// --- CIBLES CINEMATIQUES ---
double target_V = 0; double target_W = 0;
double current_V = 0; double current_W = 0;

double accel_V_step = (0.16 / fe); 
double decel_V_step = (0.22 / fe); 
double accel_W_step = (0.5  / fe); 

double rpm1_filtered = 0; double rpm2_filtered = 0;
double errorSum1 = 0, lastError1 = 0;
double errorSum2 = 0, lastError2 = 0;
volatile long tick1 = 0; volatile long tick2 = 0;
int plotCounter = 0;

// --- INTERRUPTIONS ---
void ISR_Enc1A() { if (digitalRead(ENC1_A) == digitalRead(ENC1_B)) tick1--; else tick1++; }
void ISR_Enc1B() { if (digitalRead(ENC1_A) == digitalRead(ENC1_B)) tick1++; else tick1--; }
void ISR_Enc2A() { if (digitalRead(ENC2_A) == digitalRead(ENC2_B)) tick2++; else tick2--; }
void ISR_Enc2B() { if (digitalRead(ENC2_A) == digitalRead(ENC2_B)) tick2--; else tick2++; }

void setMotorPWM(int pwm, int pinPWM, int pinDIR) {
  pwm = constrain(pwm, -255, 255);
  if (pwm > 0 && pwm < PWM_DEADBAND) pwm = PWM_DEADBAND;
  if (pwm < 0 && pwm > -PWM_DEADBAND) pwm = -PWM_DEADBAND;
  if (abs(pwm) < 5) pwm = 0;
  if (pinDIR == M2_DIR) pwm = -pwm;
  if (pwm >= 0) { digitalWrite(pinDIR, LOW); analogWrite(pinPWM, abs(pwm)); }
  else          { digitalWrite(pinDIR, HIGH); analogWrite(pinPWM, abs(pwm)); }
}

float lireVoltage() {
  int raw = analogRead(PIN_BATTERIE);
  return (raw * 5.0 / 1024.0) * RATIO_CAPTEUR;
}

int calculerPourcentage(float v) {
  float p = (v - VOLT_MIN) / (VOLT_MAX - VOLT_MIN) * 100.0;
  return constrain((int)p, 0, 100);
}

// --- MPU-6050 INIT ---
void mpuInit() {
  // Réveil du capteur
  Wire.beginTransmission(MPU_ADDR);
  Wire.write(0x6B); Wire.write(0x00);
  Wire.endTransmission(true);
  // DLPF à 44 Hz
  Wire.beginTransmission(MPU_ADDR);
  Wire.write(0x1A); Wire.write(0x03);
  Wire.endTransmission(true);
  // Gyro ±250°/s
  Wire.beginTransmission(MPU_ADDR);
  Wire.write(0x1B); Wire.write(0x00);
  Wire.endTransmission(true);
  // Accel ±2g (par défaut)
  Wire.beginTransmission(MPU_ADDR);
  Wire.write(0x1C); Wire.write(0x00);
  Wire.endTransmission(true);

  // Vérification WHO_AM_I
  Wire.beginTransmission(MPU_ADDR);
  Wire.write(0x75); Wire.endTransmission(false);
  Wire.requestFrom(MPU_ADDR, (uint8_t)1, (uint8_t)true);
  uint8_t who = Wire.read();
  mpu_ok = (who == 0x68);
  Serial.print("MPU WHO_AM_I=0x"); Serial.print(who, HEX);
  Serial.println(mpu_ok ? " OK" : " FAIL");
}

// --- Lecture gyro XYZ (burst read — roll, pitch, yaw) ---
// X = roll rate, Y = pitch rate → detect floor bump tilting
// Z = yaw rate → used for odometry divergence check
// Turns only affect Z.  Tilts only affect X/Y.  No interference.
void mpuReadGyroXYZ(double &gx, double &gy, double &gz) {
  Wire.beginTransmission(MPU_ADDR);
  Wire.write(0x43);  // GYRO_XOUT_H — burst read all 3 axes (6 bytes)
  Wire.endTransmission(false);
  Wire.requestFrom(MPU_ADDR, (uint8_t)6, (uint8_t)true);
  int16_t rx = (Wire.read() << 8) | Wire.read();
  int16_t ry = (Wire.read() << 8) | Wire.read();
  int16_t rz = (Wire.read() << 8) | Wire.read();
  gx = (rx / 131.0) * PI / 180.0;  // rad/s
  gy = (ry / 131.0) * PI / 180.0;
  gz = (rz / 131.0) * PI / 180.0;
}

// --- Lecture accélération Z ---
double mpuReadAccelZ() {
  Wire.beginTransmission(MPU_ADDR);
  Wire.write(0x3F);
  Wire.endTransmission(false);
  Wire.requestFrom(MPU_ADDR, (uint8_t)2, (uint8_t)true);
  int16_t az = (Wire.read() << 8) | Wire.read();
  return az / 16384.0;  // en g
}

// --- Calibration au démarrage (robot immobile) ---
void calibrateSensors() {
  if (!mpu_ok) return;
  Serial.println("CALIBRATION - Ne pas bouger le robot pendant 2 sec...");
  const int N = 500;
  double sum_gx = 0, sum_gy = 0, sum_gz = 0;
  double sum_a = 0;
  for (int i = 0; i < N; i++) {
    double gx, gy, gz;
    mpuReadGyroXYZ(gx, gy, gz);
    sum_gx += gx; sum_gy += gy; sum_gz += gz;
    sum_a += mpuReadAccelZ();
    delay(4);
  }
  gyro_bias_x = sum_gx / N;
  gyro_bias_y = sum_gy / N;
  gyro_bias_z = sum_gz / N;
  accel_z_baseline = sum_a / N;
  accel_z_filtered = accel_z_baseline;
  Serial.print("Biais gyro X="); Serial.print(gyro_bias_x, 5);
  Serial.print(" Y="); Serial.print(gyro_bias_y, 5);
  Serial.print(" Z="); Serial.print(gyro_bias_z, 5);
  Serial.print(" | Baseline accel Z="); Serial.println(accel_z_baseline, 3);
}
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

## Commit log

2026-05-02 Initial commit — E-Wslni Autonomous Campus Guide Robot
    [Arduino Mega 2560.SLDPRT, Arduino Mega 2560.step, Assem support arduino.SLDASM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]
2026-05-02 fix: equalize robot/CAD photo sizes, correct kinematics to differential drive
2026-05-02 docs: correct technical specs from Dossier de Definition (differential drive, Mini PC, TF tree, battery, telemetry freq)
